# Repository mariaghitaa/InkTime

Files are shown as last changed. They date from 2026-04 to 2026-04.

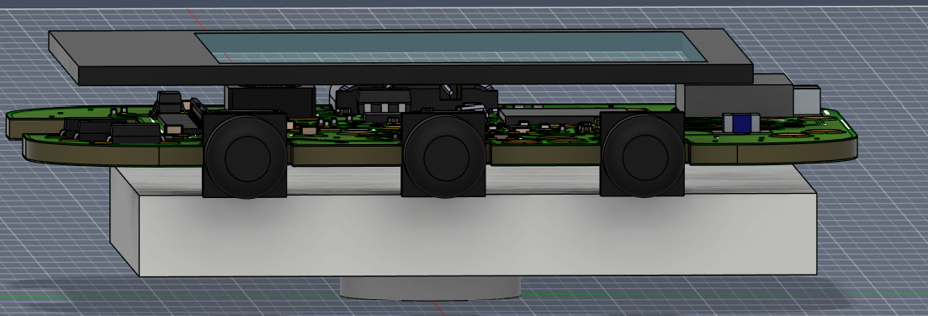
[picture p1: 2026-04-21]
Images/InkTime_asm_without_case.png

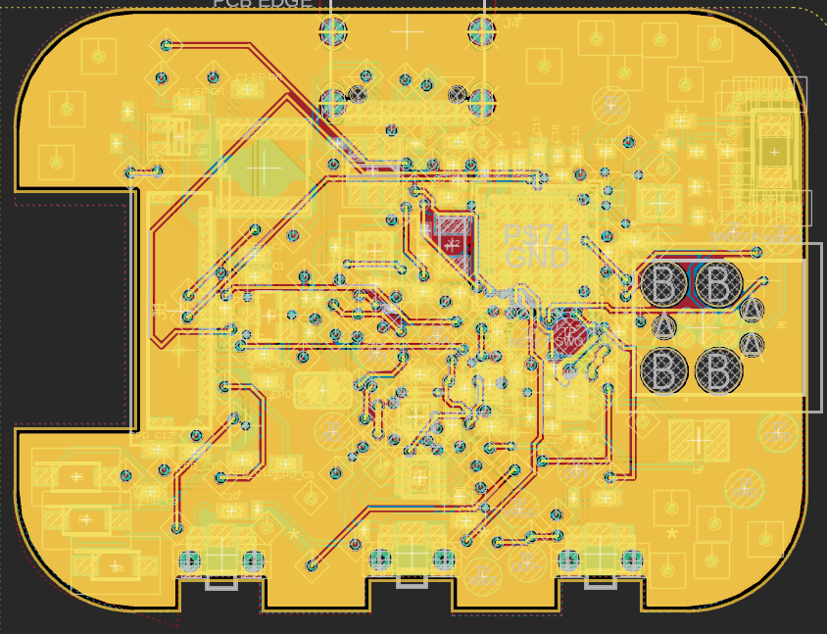
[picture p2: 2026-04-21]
Images/pcb_2D_extralayer.png

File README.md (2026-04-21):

# Proiect InkTime Smartwatch

**Student:** Ghița Maria  
**Grupa:** 331CC

## 1. Descrierea Conceptului

InkTime este un dispozitiv purtabil bazat pe microcontrolerul **nRF52840**, conceput pentru a maximiza autonomia prin utilizarea unui ecran de tip **E-Paper (EPD)** de 1.54 inch. Spre deosebire de ecranele clasice, tehnologia E-Paper consumă energie doar la împrospătarea imaginii, oferind o vizibilitate excelentă în lumină naturală și un mod de operare "Always-on" extrem de eficient.

## 2. Diagrama Bloc (Hardware Architecture)

```text
                                  SISTEM INTELIGENT INKTIME
      SURSA ENERGIE              ___________________________                PERIFERICE (I/O)
    _________________           |                           |             ____________________
   |                 |          |      nRF52840 (SoC)       |            |                    |
   | USB-C Connector |--- 5V ---|   Bluetooth 5.0 Low En.   |--- SPI --->|  E-PAPER DISPLAY   |
   |   (Incarcare)   |          |___________________________|    Bus     |  (1.54" 24-pin)    |
   |_________________|           |  P0.02 (SCK)             |            |____________________|
            |                    |  P0.03 (MOSI)            |
            v                    |  P0.15 (DC)              |             ____________________
    _________________            |  P0.16 (RST)             |            |                    |
   | BQ25180 Charger |           |  P0.17 (BUSY)            |            |                    |
   | (Mngmnt Baterie)|-- VBAT -- |                          |            |                    |
   |_________________|    |      |  P0.26 (SDA) <---I2C---> |----------->|  ACCEL. (BMA421)   |
            ^             |      |  P0.27 (SCL)    Bus      |----------->|  GAUGE (MAX17048)  |
            |             |      |                          |----------->|  DRV2605 (Haptic)  |
    ________|________     |      |                          |            |____________________|
   | Li-Po Battery   |----+      |                          |
   |    250 mAh      |    |      |  P1.11 (PWM) ------------|----------->[ SHAKER / MOTOR ]
   |_________________|    |      |                          |
            |             |      |  P0.13 (UP)              |             ____________________
            v             |      |  P0.14 (ENTER) <---GPIO--|------------|   3x BUTOANE       |
    _________________     |      |  P1.02 (DOWN)            |            |   NAVIGATIE        |
   | RT6160A (Buck-B)|<---+      |                          |            |____________________|
   |  Output: 3.3V   |-----------|  P0.00 / P0.01 ----------|----------->[ CRYSTAL 32.768kHz]
   |_________________|           |  (LFXO Clock)            |            
                                 |__________________________|
```

## 3. Descriere Detaliată Hardware

### 3.1 Microcontroller — nRF52840

Inima sistemului este microcontrollerul Nordic nRF52840, care gestionează toate perifericele, comunicația wireless și logica aplicației.

- **CPU:** ARM Cortex-M4F la frecvență maximă de 64 MHz
- **Memorie:** 1 MB Flash, 256 KB RAM
- **Alimentare:** 3.3V (furnizat de regulatorul DC-DC)
- **Conectivitate:** Bluetooth 5.0 Low Energy, USB 2.0
- **Periferice utilizate:** SPI, I2C, GPIO, PWM, USB

Antena ceramică 2450AT18B100E (2.4 GHz) este acordată printr-o rețea de matching LC calculată pentru impedanță de 50Ω, asigurând performanță RF optimă.

### 3.2 Sistemul de Alimentare

#### Baterie LiPo

Dispozitivul este alimentat de o baterie LiPo cu tensiune nominală de 3.7V (max 4.2V) și capacitate de 250 mAh.

#### Încărcător — BQ25180

Încărcarea bateriei se realizează prin circuitul BQ25180 care primește alimentare de la conectorul USB-C. Acesta oferă management complet al ciclului de încărcare, protecție termică și reglare a curentului de încărcare pentru bateria LiPo. Comunicarea cu MCU-ul se face prin I2C, permițând configurarea parametrilor de încărcare din software.

#### Convertor DC-DC — RT6160A

Regulatorul buck-boost RT6160A convertește tensiunea variabilă a bateriei (3.0–4.2V) într-o ieșire stabilă de 3.3V. Alegerea unui convertor buck-boost (în loc de un LDO) asigură funcționarea stabilă a întregului sistem inclusiv când bateria este aproape descărcată. Tensiunea de 3.3V alimentează MCU-ul, senzorii, display-ul și toate celelalte periferice.

#### Fuel Gauge — MAX17048

Monitorizarea stării bateriei este realizată de MAX17048, care utilizează algoritmul ModelGauge pentru a estima nivelul de încărcare (State of Charge) fără a necesita rezistență de shunt. Comunicarea se face prin I2C, iar pinul ALERT (conectat la P0.10 pe MCU) poate genera o întrerupere atunci când nivelul bateriei scade sub un prag configurat.

### 3.3 Interfața USB-C

Conectorul USB Type-C (KH-TYPE-C-16P) îndeplinește două roluri: alimentare pentru încărcarea bateriei și comunicație USB 2.0 cu MCU-ul. Liniile de date D+ și D- sunt conectate la pinii USB dedicați ai nRF52840, iar pe liniile CC1/CC2 sunt montate rezistențe pull-down de 5.1kΩ pentru identificarea rolului de device. Protecția ESD pe liniile USB este asigurată de circuitul USBLC6-2SC6Y.

### 3.4 Display E-Paper

Display-ul e-paper de 1.54 inch este conectat prin FPC (conector Molex 503480-2400, 24-pin). Principalele avantaje ale tehnologiei e-paper pentru un smartwatch sunt consumul aproape zero în idle (imaginea persistă fără alimentare) și lizibilitatea excelentă în lumina solară.

Comunicarea cu MCU-ul se face prin **SPI** cu următoarele semnale:

- **MOSI** — transmite date și comenzi către display
- **SCK** — semnal de clock pentru sincronizarea transferului
- **DC** — diferențiază între comenzi și date
- **RST** — resetare hardware a controllerului display-ului
- **BUSY** — semnalizează că display-ul procesează un refresh

Alimentarea display-ului este controlată de un PFET Si2301CDS, permițând oprirea completă a panoului pentru economisirea energiei. Circuitul driver integrat pe placa EPD generează tensiunile înalte necesare actualizării cernelii electronice.

### 3.5 Accelerometru — BMA421

Senzorul BMA421 oferă măsurători de accelerație pe 3 axe și este utilizat pentru:

- detecția mișcării și a gesturilor (ridicare încheietură)
- funcționalitate de pedometru
- activarea ecranului din sleep

Comunicarea se face prin **I2C** (SDA, SCL), iar senzorul dispune de două linii de întrerupere (INT1, INT2) care permit trezirea MCU-ului din modul de consum redus doar când apare un eveniment relevant.

### 3.6 Driver Haptic — DRV2605

Driverul DRV2605 controlează motorul de vibrație (LRA/ERM) și oferă o bibliotecă de peste 100 de efecte haptice predefinite. Configurarea efectelor se realizează prin **I2C**, iar activarea vibrației se poate face și direct printr-un semnal digital pe pinul EN, fără a necesita comunicare I2C continuă.

### 3.7 Butoane

Trei butoane tactile (EVP-AKB31A) sunt conectate la pini GPIO ai MCU-ului cu rezistențe pull-up de 10kΩ. La apăsare, butonul conectează pinul la masă, iar MCU-ul detectează tranziția HIGH→LOW. Fiecare buton are un condensator de debouncing de 1µF.

- **UP** — navigare sus în meniu
- **ENTER** — selecție / confirmare
- **DOWN** — navigare jos în meniu

### 3.8 Interfața SWD

Programarea și debugging-ul firmware-ului se realizează prin interfața SWD (Serial Wire Debug) accesibilă printr-un header Tag-Connect TC2030-IDC (6-pin). Semnalele utilizate: SWDIO, SWDCLK, RESET, VCC, GND.

## 4. Bill of Materials (BOM)

| Componentă | Package | JLC Parts | Datasheet |
|---|---|---|---|
| Antenna (2450AT18B100E) | SMD 3216 | [C5179427](https://jlcpcb.com/partdetail/C5179427) | [Datasheet](https://www.johansontechnology.com/datasheets/2450AT18B100/2450AT18B100.pdf) |
| Charger (BQ25120YBGR) | DSBGA-9 | [C1682423](https://jlcpcb.com/partdetail/C1682423) | [Datasheet](https://www.ti.com/lit/ds/symlink/bq25180.pdf) |
| Haptic Driver (DRV2605LDGSR) | VSSOP-10 | [C527464](https://jlcpcb.com/partdetail/C527464) | [Datasheet](https://www.ti.com/lit/ds/symlink/drv2605l.pdf) |
| Buttons (EVP-AKB31A) | SMD tactile | [C2845028](https://jlcpcb.com/partdetail/C2845028) | [Datasheet](https://industrial.panasonic.com/cdbs/www-data/pdf/ATV0000/ATV0000CE3.pdf) |
| USB Type-C Connector (KH-TYPE-C-16P) | 16-pin SMD | [C2765186](https://jlcpcb.com/partdetail/C2765186) | [Datasheet](https://datasheet.lcsc.com/lcsc/2012121836_Kinghelm-KH-TYPE-C-16P_C2765186.pdf) |
| Fuel Gauge (MAX17048G+T10) | DFN-8 (2x2) | [C2682616](https://jlcpcb.com/partdetail/C2682616) | [Datasheet](https://www.analog.com/media/en/technical-documentation/data-sheets/MAX17048-MAX17049.pdf) |
| MCU (nRF52840-QIAA-R) | aQFN73 (7x7) | [C190794](https://jlcpcb.com/partdetail/C190794) | [Datasheet](https://docs.nordicsemi.com/) |
| Accelerometer (BMA421) | LGA-12 (2x2) | [C5242966](https://jlcpcb.com/partdetail/C5242966) | [Datasheet](https://www.bosch-sensortec.com/media/boschsensortec/downloads/datasheets/bst-bma421-ds004.pdf) |
| FPC Connector (Molex 503480-2400) | 24-pin 0.5mm FPC | [C2857168](https://jlcpcb.com/partdetail/C2857168) | [Datasheet](https://www.molex.com/en-us/products/part-detail/5034802400) |
| Buck-Boost Regulator (RT6160AWSC) | WLCSP-15 | [C7065276](https://jlcpcb.com/partdetail/C7065276) | [Datasheet](https://www.richtek.com/assets/product_file/RT6160A/DS6160A-05.pdf) |
| Vibration Motor (LCM102733605F) | Wire leads | [C7528006](https://jlcpcb.com/partdetail/C7528006) | [Datasheet](https://datasheet.lcsc.com/lcsc/2310131633_LCM-LCM1027B3605F_C7528806.pdf) |
| PFET EPD power (Si2301CDS) | SOT-23 | [C10487](https://jlcpcb.com/partdetail/C10487) | [Datasheet](https://www.vishay.com/docs/68749/si2301cds.pdf) |
| USB ESD Protection (USBLC6-2SC6Y) | SOT-23-6 | [C7519](https://jlcpcb.com/partdetail/C7519) | [Datasheet](https://www.st.com/resource/en/datasheet/usblc6-2.pdf) |
| SWD Debug Header (TC2030-IDC) | Tag-Connect 6-pin | - | - |
| Crystal 32 MHz | 2016 | - | - |
| Crystal 32.768 kHz | 3215 | - | - |
| Resistors x 2 10k | 0201 | - | - |
| Resistors x 2 5.1k | 0201 | - | - |
| Capacitors x 4 12pF | 0201 | - | - |
| Capacitors x 5 100nF | 0201 | - | - |
| Capacitors x 5 4.7uF | 0402 | - | - |
| Capacitors x 2 22uF | 0402 | - | - |
| Capacitors x 12 1uF | 0402 | - | - |
| Inductor 0.47uH | 2012 | - | - |
| Inductor 10uH | 0402 | - | - |
| E-Paper Display 1.54 inch | 24-pin FPC | - | - |
| LiPo Battery 250 mAh | - | - | - |

## 5. Alocare Pini nRF52840

### 5.1 Interfața SPI — Display E-Paper

| Pin | Semnal | Rol |
|-----|---|-----|
| P0.02 | SCK | Clock SPI pentru transfer date către display |
| P0.03 | MOSI | Linie de date master → display |
| P0.15 | DC | Selecție date/comandă |
| P0.16 | RST | Reset hardware controller display |
| P0.17 | BUSY | Stare display (ocupat/liber) |

SPI a fost ales deoarece actualizarea display-ului e-paper necesită transferuri rapide de blocuri mari de date (framebuffer complet). Pinii P0.02 și P0.03 suportă mapare SPI flexibilă pe nRF52840, iar P0.15–P0.17 sunt pini GPIO adiacenți, simplificând rutarea pe PCB.

### 5.2 Magistrala I2C — Senzori și Management Energetic

| Pin | Semnal | Dispozitive conectate |
|-----|---|---|
| P0.26 | SDA | BMA421, DRV2605, MAX17048, RT6160A, BQ25180 |
| P0.27 | SCL | BMA421, DRV2605, MAX17048, RT6160A, BQ25180 |

P0.26 și P0.27 sunt pini cu suport hardware I2C nativ (TWIM peripheral) pe nRF52840. Toate cele cinci dispozitive I2C sunt conectate pe aceeași magistrală, fiecare cu adresă unică, reducând numărul de pini utilizați. Pe liniile SDA și SCL sunt montate rezistențe pull-up la 3.3V.

### 5.3 Semnale Suplimentare Senzori

| Pin | Semnal | Rol |
|-----|---|-----|
| P0.10 | ALERT (MAX17048) | Întrerupere la nivel critic baterie, permite trezirea MCU din sleep |
| P0.22 | EN (DRV2605) | Activare directă efect haptic fără comunicație I2C |

Pinii de întrerupere ai BMA421 (INT1, INT2) sunt de asemenea conectați la MCU, permițând detecția evenimentelor de mișcare fără polling continuu.

### 5.4 Butoane — GPIO

| Pin | Funcție | Detalii |
|-----|---|---|
| P0.13 | Button UP | Pull-up 10kΩ, debounce 1µF |
| P0.14 | Button ENTER | Pull-up 10kΩ, debounce 1µF |
| P1.02 | Button DOWN | Pull-up 10kΩ, debounce 1µF |

Pinii sunt configurați ca intrări digitale. Alegerea lor a ținut cont de disponibilitatea pe portul GPIO și de rutarea optimă pe PCB. Apăsarea butonului trage pinul la GND, iar MCU-ul detectează frontul descrescător.

### 5.5 USB

| Pin | Semnal |
|-----|---|
| D+ (dedicat) | Linie de date USB+ |
| D- (dedicat) | Linie de date USB- |
| VBUS (dedicat) | Detecție alimentare USB |

Pinii USB sunt dedicați pe nRF52840 (nu sunt GPIO remapabili) și sunt conectați la conectorul USB-C prin circuitul de protecție ESD USBLC6-2SC6Y.

### 5.6 Alte Semnale

| Pin | Semnal | Rol |
|-----|---|-----|
| P0.00 | XL1 | Cristal 32.768 kHz — clock RTC pentru timekeeping în sleep |
| P0.01 | XL2 | Cristal 32.768 kHz — pereche oscilator LFXO |
| SWDIO | SWD Data | Programare și debug firmware |
| SWDCLK | SWD Clock | Clock interfață debug |

P0.00 și P0.01 sunt singurii pini pe nRF52840 dedicați oscilatorului low-frequency (LFXO). Cristalul de 32.768 kHz permite funcționarea RTC-ului cu consum extrem de redus (~2 µA) în modul System ON sleep.

### 5.7 Criterii de Alocare

Distribuția pinilor a fost realizată ținând cont de:

- utilizarea interfețelor hardware native ale MCU-ului (SPI, I2C, USB, LFXO)
- gruparea semnalelor conexe pe pini adiacenți pentru simplificarea traseelor PCB
- disponibilitatea funcțiilor de întrerupere hardware pe pinii aleși
- minimizarea consumului prin posibilitatea de wake-up din sleep pe oricare din pinii GPIO utilizați

## 6. Estimare Consum de Energie

### Consum per componentă

| Componentă | Mod Sleep / Idle | Mod Activ |
|---|---|---|
| nRF52840 | ~2–5 µA (System ON sleep) | ~5–10 mA (CPU activ, radio oprit) |
| nRF52840 (BLE TX) | — | ~4.8 mA (transmisie la 0 dBm) |
| Display E-Paper | ~0 µA (imagine statică) | ~10–20 mA (în timpul refresh-ului) |
| BMA421 | ~14 µA (low-power mode) | ~160 µA (normal mode) |
| MAX17048 | ~50 µA (măsurare continuă) | ~50 µA |
| DRV2605 + Motor | ~0 µA (standby) | ~100 mA (vibrație activă) |
| RT6160A | ~15 µA (quiescent) | depinde de sarcină |
| BQ25180 | ~1 µA (mod ship) | depinde de curentul de încărcare |

### Scenariu tipic de utilizare

În funcționare normală (ecran static, BLE inactiv, fără vibrație), consumul este dominat de MCU în sleep și senzori:

| Componentă | Consum estimat |
|---|---|
| MCU (sleep cu RTC) | ~5 µA |
| BMA421 (low-power) | ~14 µA |
| MAX17048 | ~50 µA |
| RT6160A (quiescent) | ~15 µA |
| **Total idle** | **~84 µA** |

Cu o baterie de 250 mAh, autonomia teoretică maximă în idle este:

**250.000 µAh / 84 µA ≈ 2.976 ore ≈ 124 zile**

Într-un scenariu realist (cu refresh-uri periodice ale ecranului, citiri BLE ocazionale și notificări haptice), consumul mediu estimat este de aproximativ **0.5–1 mA**, rezultând o autonomie de **10–20 zile** — competitivă cu smartwatch-urile e-paper comerciale.

## 7. Jurnal de Design și Fabricație

- **Proiectare PCB:** S-a optat pentru o configurație de 4 straturi (Signal-GND-VCC-Signal) pentru a asigura ecranarea electromagnetică și integritatea semnalului RF.
- **Miniaturizare:** Toate componentele pasive de decuplare din jurul nRF52840 sunt de mărime 0201, reducând dimensiunea finală a plăcii.
- **Design Mecanic:** Carcasa a fost modelată în Fusion 360 pentru a integra PCB-ul și bateria de 250mAh într-un profil compact, utilizând toleranțe strânse pentru montarea prin presare.

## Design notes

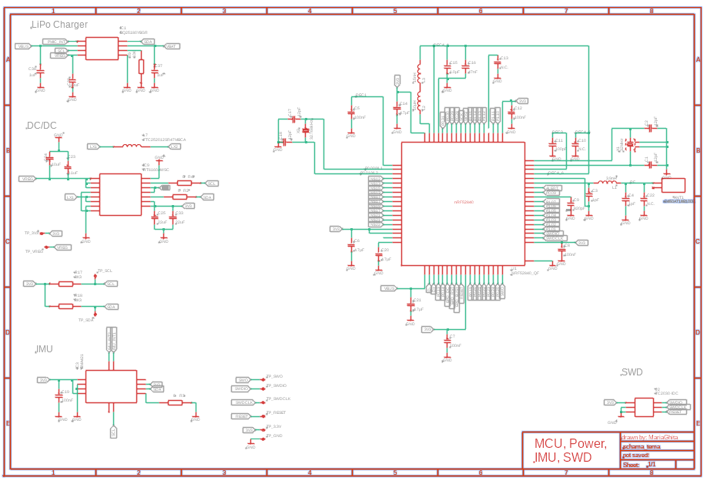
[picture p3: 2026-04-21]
Images/schematic_1.png

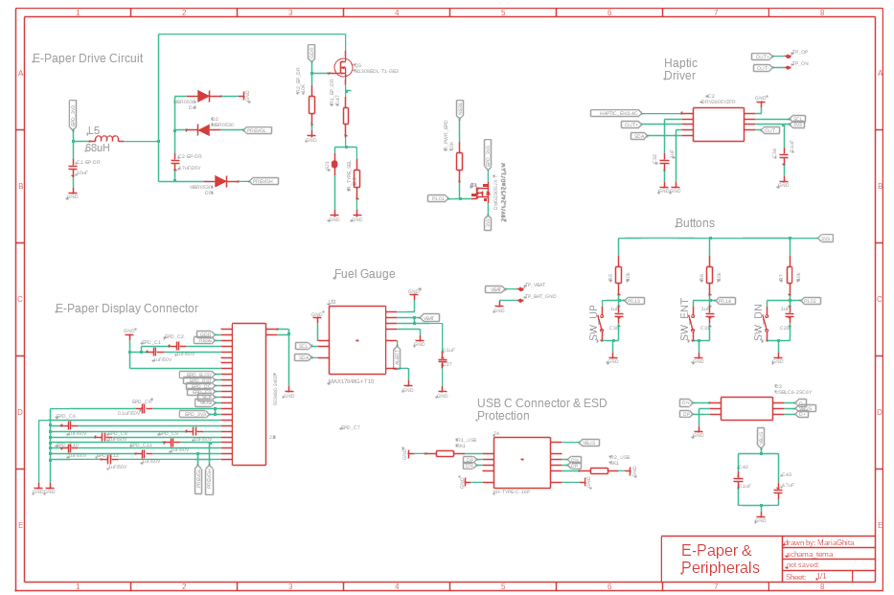
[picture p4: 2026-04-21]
Images/schematic_2.png

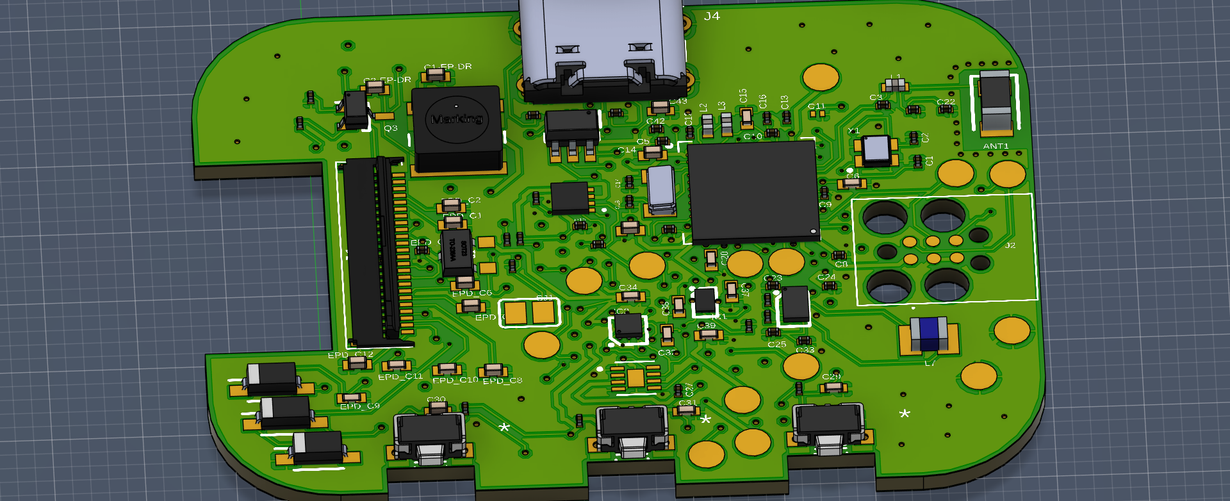
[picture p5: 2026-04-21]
Images/pcb_3D_top.png

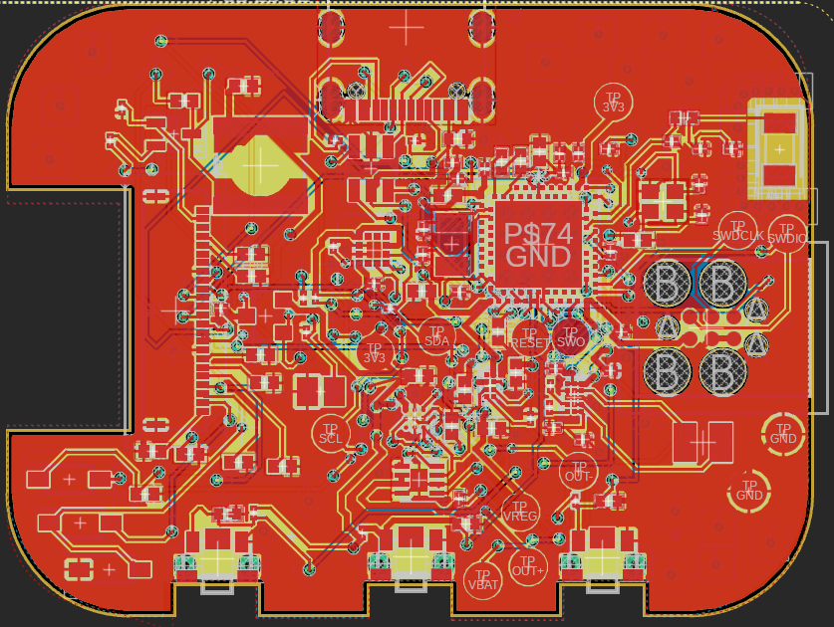
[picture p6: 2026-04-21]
Images/pcb_2D_top.png

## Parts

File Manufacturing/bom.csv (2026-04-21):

Part | Value | Device | Package | Description | ARROW_PART_NUMBER | ARROW_PRICE-STOCK | AVAILABILITY | CHECK_PRICES | COPYRIGHT | DESCRIPTION | DIGI-KEY_PART_NUMBER_1 | DIGI-KEY_PART_NUMBER_2 | DIGI-KEY_PART_NUMBER_3 | HEIGHT | JLCPCB | MANUFACTURER_NAME | MANUFACTURER_PART_NUMBER | MF | MFR_NAME | MOUSER_PART_NUMBER | MOUSER_PRICE-STOCK | MP | PACKAGE | POPULARITY | PRICE | PROD_ID | PURCHASE-URL | SNAPEDA_LINK | TP_SIGNAL_NAME | VALUE
ANT1 | 2450AT18B100E | 2450AT18B100E_2450AT18B100E | 2450AT18B100E_ANTC3216X140N | Antennas 2.45GHz ANTENNA | 2450AT18B100E | https://www.arrow.com/en/products/2450at18b100e/johanson-dielectrics?utm_currency=USD&region=nac |  |  |  | Antennas 2.45GHz ANTENNA |  |  |  | 1.4mm |  | JOHANSON TECHNOLOGY | 2450AT18B100E |  |  | 609-2450AT18B100E | https://www.mouser.co.uk/ProductDetail/Johanson-Technology/2450AT18B100E?qs=yCnrNFeXz%252Bh5MFsFIXGZGA%3D%3D
C1 | 12pF | NORDIC_NRF_3_CAPACITOR_0201_L | NORDIC_NRF_3_RESC0201_L | Generic chip capacitor
C1-EP-DR | 10uF | PERFECT_0402_CAP_0402 | PERFECT_0402_0402 | 0402 (1005 Metric)
C2 | 12pF | NORDIC_NRF_3_CAPACITOR_0201_L | NORDIC_NRF_3_RESC0201_L | Generic chip capacitor
C2-EP-DR | 4.7uF/25V | PERFECT_0402_CAP_0402 | PERFECT_0402_0402 | 0402 (1005 Metric)
C3 | 1pF | NORDIC_NRF_3_CAPACITOR_0201_L | NORDIC_NRF_3_RESC0201_L | Generic chip capacitor
C4 | 1pF | NORDIC_NRF_3_CAPACITOR_0201_L | NORDIC_NRF_3_RESC0201_L | Generic chip capacitor
C5 | 100nF | NORDIC_NRF_3_CAPACITOR_0201_L | NORDIC_NRF_3_RESC0201_L | Generic chip capacitor
C6 | 4.7µF | PERFECT_0402_CAP_0402 | PERFECT_0402_0402 | 0402 (1005 Metric)
C7 | 100nF | NORDIC_NRF_3_CAPACITOR_0201_L | NORDIC_NRF_3_RESC0201_L | Generic chip capacitor
C8 | 100nF | NORDIC_NRF_3_CAPACITOR_0201_L | NORDIC_NRF_3_RESC0201_L | Generic chip capacitor
C9 | 820pF | NORDIC_NRF_3_CAPACITOR_0201_L | NORDIC_NRF_3_RESC0201_L | Generic chip capacitor
C10 | N.C. | NORDIC_NRF_3_CAPACITOR_0201_L | NORDIC_NRF_3_RESC0201_L | Generic chip capacitor
C11 | 100pF | NORDIC_NRF_3_CAPACITOR_0201_L | NORDIC_NRF_3_RESC0201_L | Generic chip capacitor
C12 | 100nF | NORDIC_NRF_3_CAPACITOR_0201_L | NORDIC_NRF_3_RESC0201_L | Generic chip capacitor
C13 | N.C. | NORDIC_NRF_3_CAPACITOR_0201_L | NORDIC_NRF_3_RESC0201_L | Generic chip capacitor
C14 | 4.7µF | PERFECT_0402_CAP_0402 | PERFECT_0402_0402 | 0402 (1005 Metric)
C15 | 1.0µF | PERFECT_0402_CAP_0402 | PERFECT_0402_0402 | 0402 (1005 Metric)
C16 | 47nF | NORDIC_NRF_3_CAPACITOR_0201_L | NORDIC_NRF_3_RESC0201_L | Generic chip capacitor
C17 | 12pF | NORDIC_NRF_3_CAPACITOR_0201_L | NORDIC_NRF_3_RESC0201_L | Generic chip capacitor
C18 | 12pF | NORDIC_NRF_3_CAPACITOR_0201_L | NORDIC_NRF_3_RESC0201_L | Generic chip capacitor
C19 | 100nF | NORDIC_NRF_3_CAPACITOR_0201_L | NORDIC_NRF_3_RESC0201_L | Generic chip capacitor
C20 | 4.7µF | PERFECT_0402_CAP_0402 | PERFECT_0402_0402 | 0402 (1005 Metric)
C21 | 4.7µF | PERFECT_0402_CAP_0402 | PERFECT_0402_0402 | 0402 (1005 Metric)
C22 | N.C. | NORDIC_NRF_3_CAPACITOR_0201_L | NORDIC_NRF_3_RESC0201_L | Generic chip capacitor
C23 | 0.1uF | NORDIC_NRF_3_CAPACITOR_0201_L | NORDIC_NRF_3_RESC0201_L | Generic chip capacitor
C24 | 10uF | NORDIC_NRF_3_CAPACITOR_0201_L | NORDIC_NRF_3_RESC0201_L | Generic chip capacitor
C25 | 22uF | NORDIC_NRF_3_CAPACITOR_0201_L | NORDIC_NRF_3_RESC0201_L | Generic chip capacitor
C27 | 0.1uF | NORDIC_NRF_3_CAPACITOR_0201_L | NORDIC_NRF_3_RESC0201_L | Generic chip capacitor
C29 | 1uF | NORDIC_NRF_3_CAPACITOR_0402_L | NORDIC_NRF_3_RESC0402_L | Generic chip capacitor
C30 | 1uF | NORDIC_NRF_3_CAPACITOR_0402_L | NORDIC_NRF_3_RESC0402_L | Generic chip capacitor
C31 | 1uF | NORDIC_NRF_3_CAPACITOR_0402_L | NORDIC_NRF_3_RESC0402_L | Generic chip capacitor
C32 | 1uF | PERFECT_0402_CAP_0402 | PERFECT_0402_0402 | 0402 (1005 Metric)
C33 | 22uF | NORDIC_NRF_3_CAPACITOR_0201_L | NORDIC_NRF_3_RESC0201_L | Generic chip capacitor
C34 | 0.1uF | PERFECT_0402_CAP_0402 | PERFECT_0402_0402 | 0402 (1005 Metric)
C37 | 1uF | PERFECT_0402_CAP_0402 | PERFECT_0402_0402 | 0402 (1005 Metric)
C38 | 1uF | PERFECT_0402_CAP_0402 | PERFECT_0402_0402 | 0402 (1005 Metric)
C39 | 10uF | PERFECT_0402_CAP_0402 | PERFECT_0402_0402 | 0402 (1005 Metric)
C42 | 0.1uF | NORDIC_NRF_3_CAPACITOR_0201_L | NORDIC_NRF_3_RESC0201_L | Generic chip capacitor
C43 | 4.7uF | NORDIC_NRF_3_CAPACITOR_0402_L | NORDIC_NRF_3_RESC0402_L | Generic chip capacitor
D2 | MBR0530 | ESP32_C6_LIBRARY_5_MBR0530 | ESP32_C6_LIBRARY_5_SOD3716X135N | ON SEMICONDUCTOR - MBR0530 - DIODE, SCHOTTKY, 0.5A, 30V, SOD-123 |  |  | In Stock | https://www.snapeda.com/parts/MBR0530/Onsemi/view-part/?ref=eda |  | Diode Schottky 30 V 500mA Surface Mount SOD-123 |  |  |  |  |  |  |  | ON Semiconductor |  |  |  | MBR0530 | SOD-123-2 ON Semiconductor |  | None |  | https://www.snapeda.com/api/url_track_click_mouser/?unipart_id=179458&manufacturer=ON Semiconductor&part_name=MBR0530&search_term=None | https://www.snapeda.com/parts/MBR0530/Onsemi/view-part/?ref=snap
D3 | USBLC6-2SC6Y | ESP32_C6_LIBRARY_3_USBLC6-2SC6Y | ESP32_C6_LIBRARY_3_SOT95P280X145-6N | Low Cap. ESD Protection Auto SOT-23-6 STMicroelectronics USBLC6-2SC6Y, Dual Uni-Directional TVS Diode Array, 6-Pin SOT-23 |  |  | In Stock | https://www.snapeda.com/parts/USBLC6-2SC6Y/STMicroelectronics/view-part/?ref=eda |  | 17V Clamp 5A (8/20µs) Ipp Tvs Diode Surface Mount SOT-23-6 |  |  |  |  |  |  |  | STMicroelectronics |  |  |  | USBLC6-2SC6Y | SOT-23-6 STMicroelectronics |  | None |  |  | https://www.snapeda.com/parts/USBLC6-2SC6Y/STMicroelectronics/view-part/?ref=snap
D4 | MBR0530 | ESP32_C6_LIBRARY_5_MBR0530 | ESP32_C6_LIBRARY_5_SOD3716X135N | ON SEMICONDUCTOR - MBR0530 - DIODE, SCHOTTKY, 0.5A, 30V, SOD-123 |  |  | In Stock | https://www.snapeda.com/parts/MBR0530/Onsemi/view-part/?ref=eda |  | Diode Schottky 30 V 500mA Surface Mount SOD-123 |  |  |  |  |  |  |  | ON Semiconductor |  |  |  | MBR0530 | SOD-123-2 ON Semiconductor |  | None |  | https://www.snapeda.com/api/url_track_click_mouser/?unipart_id=179458&manufacturer=ON Semiconductor&part_name=MBR0530&search_term=None | https://www.snapeda.com/parts/MBR0530/Onsemi/view-part/?ref=snap
D5 | MBR0530 | ESP32_C6_LIBRARY_5_MBR0530 | ESP32_C6_LIBRARY_5_SOD3716X135N | ON SEMICONDUCTOR - MBR0530 - DIODE, SCHOTTKY, 0.5A, 30V, SOD-123 |  |  | In Stock | https://www.snapeda.com/parts/MBR0530/Onsemi/view-part/?ref=eda |  | Diode Schottky 30 V 500mA Surface Mount SOD-123 |  |  |  |  |  |  |  | ON Semiconductor |  |  |  | MBR0530 | SOD-123-2 ON Semiconductor |  | None |  | https://www.snapeda.com/api/url_track_click_mouser/?unipart_id=179458&manufacturer=ON Semiconductor&part_name=MBR0530&search_term=None | https://www.snapeda.com/parts/MBR0530/Onsemi/view-part/?ref=snap
EPD_C1 | 1uF/50V | PERFECT_0402_CAP_0402 | PERFECT_0402_0402 | 0402 (1005 Metric)
EPD_C2 | 1uF/50V | PERFECT_0402_CAP_0402 | PERFECT_0402_0402 | 0402 (1005 Metric)
EPD_C5 | 0.1uF/50V | NORDIC_NRF_3_CAPACITOR_0201_L | NORDIC_NRF_3_RESC0201_L | Generic chip capacitor
EPD_C6 | 1uF/50V | PERFECT_0402_CAP_0402 | PERFECT_0402_0402 | 0402 (1005 Metric)
EPD_C7 | 1uF/50V | PERFECT_0402_CAP_0402 | PERFECT_0402_0402 | 0402 (1005 Metric)
EPD_C8 | 1uF/50V | PERFECT_0402_CAP_0402 | PERFECT_0402_0402 | 0402 (1005 Metric)
EPD_C9 | 1uF/50V | PERFECT_0402_CAP_0402 | PERFECT_0402_0402 | 0402 (1005 Metric)
EPD_C10 | 1uF/50V | PERFECT_0402_CAP_0402 | PERFECT_0402_0402 | 0402 (1005 Metric)
EPD_C11 | 1uF/50V | PERFECT_0402_CAP_0402 | PERFECT_0402_0402 | 0402 (1005 Metric)
EPD_C12 | 1uF/50V | PERFECT_0402_CAP_0402 | PERFECT_0402_0402 | 0402 (1005 Metric)
IC1 | BQ25180YBGR | BQ25180YBGR_BQ25180YBGR | BQ25180YBGR_BGA8C40P2X4_100X155X50 | Charger IC Lithium Ion/Polymer, Lithium Iron Phosphate 8-DSBGA (1.6x1.1) | BQ25180YBGR | https://www.arrow.com/en/products/bq25180ybgr/texas-instruments?utm_currency=USD&region=nac |  |  |  | Charger IC Lithium Ion/Polymer | Lithium Iron Phosphate 8-DSBGA (1.6x1.1) |  |  |  | 0.5mm |  | Texas Instruments | BQ25180YBGR |  |  | 595-BQ25180YBGR | https://www.mouser.co.uk/ProductDetail/Texas-Instruments/BQ25180YBGR?qs=doiCPypUmgEWjAK%252BJAX6Tw%3D%3D
IC2 | DRV2605YZFR | DRV2605YZFR_DRV2605YZFR | DRV2605YZFR_BGA9C50P3X3_144X144X62 | Haptic Driver for ERM/LRA with Built-In Library and Smart Loop Architecture | DRV2605YZFR | https://www.arrow.com/en/products/drv2605yzfr/texas-instruments?region=nac |  |  |  | Haptic Driver for ERM/LRA with Built-In Library and Smart Loop Architecture |  |  |  | 0.625mm |  | Texas Instruments | DRV2605YZFR
IC3 | BMA421 | BMA423_BMA423 | BMA423_BMA423 | Accelerometers Triaxial low-g 12bit Acceleration Sensor | BMA423 | https://www.arrow.com/en/products/bma423/bosch |  |  |  | Accelerometers Triaxial low-g 12bit Acceleration Sensor |  |  |  | 1mm |  | BOSCH | BMA423 |  |  | 262-BMA423 | https://www.mouser.co.uk/ProductDetail/Bosch-Sensortec/BMA423?qs=HXFqYaX1Q2xC%252BSgeGoX3mg%3D%3D
IC9 | RT6160AWSC | RT6160AWSC_RT6160AWSC | RT6160AWSC_BGA15C40P3X5_140X230X60 | Buck-Boost Regulator Positive Output Step-Up/Step-Down I2C DC-DC Controller IC 15-WL-CSP (BSC) (1.4x2.3) |  |  |  |  |  | Buck-Boost Regulator Positive Output Step-Up/Step-Down I2C DC-DC Controller IC 15-WL-CSP (BSC) (1.4x2.3) |  |  |  | 0.6mm |  | RICHTEK | RT6160AWSC |  |  | 835-RT6160AWSC | https://www.mouser.co.uk/ProductDetail/Richtek/RT6160AWSC?qs=amGC7iS6iy%2FLd9PSoixZXQ%3D%3D
J1 | 503480-2400 | 503480-2400_503480-2400 | 503480-2400_5034802400 | FFC & FPC Connectors 0.5mm FPC RA SMT Dual Contact 24Ckt |  |  |  |  |  | FFC & FPC Connectors 0.5mm FPC RA SMT Dual Contact 24Ckt |  |  |  | 1.87mm |  | Molex | 503480-2400 |  |  | 538-503480-2400 | https://www.mouser.co.uk/ProductDetail/Molex/503480-2400?qs=OAhjpuo3Vu7efIoxFh9AOw%3D%3D
J2 | TC2030-IDC | TC2030-IDC_TC2030-IDC | TC2030-IDC_TC2030IDC | CABLE ADAPTER 6 POS |  |  |  |  |  | CABLE ADAPTER 6 POS |  |  |  | 19mm |  | Tag Connect | TC2030-IDC
J4 | KH-TYPE-C-16P | KH-TYPE-C-16P_KH-TYPE-C-16P | KH-TYPE-C-16P_KINGHELM_KH-TYPE-C-16P | Check availability |  |  | Not in stock | https://www.snapeda.com/parts/KH-TYPE-C-16P/Kinghelm/view-part/?ref=eda |  |  |  |  |  |  |  |  |  | kinghelm |  |  |  | KH-TYPE-C-16P | None |  | None |  |  | https://www.snapeda.com/parts/KH-TYPE-C-16P/Kinghelm/view-part/?ref=snap
L1 | 3.9nH | NORDIC_NRF_2_INDUCTOR_0402_L | NORDIC_NRF_2_RESC0402_L | Generic chip inductor
L2 | 10µH | NORDIC_NRF_2_INDUCTOR_0402_L | NORDIC_NRF_2_RESC0402_L | Generic chip inductor
L3 | 15nH | NORDIC_NRF_2_INDUCTOR_0402_L | NORDIC_NRF_2_RESC0402_L | Generic chip inductor
L5 | 68uH | ESP32_C6_LIBRARY_2_744043680IND_4828-WE-TPC_WRE | ESP32_C6_LIBRARY_2_IND_4828-WE-TPC_WRE |  |  |  |  |  | Copyright (C) 2024 Ultra Librarian. All rights reserved. |  |  |  |  |  |  |  | 744043680 |  | Wurth Electronics
L7 | FTC252012SR47MBCA | MLP2016SR47MT0S1_FTC252012SR47MBCA | MLP2016SR47MT0S1_INDC2016X100N | SMD / SMT Inductors (Coils), L=0.47?H, L x W x T : |  |  |  |  |  | SMD / SMT Inductors (Coils) | L=0.47?H | L x W x T : |  |  |  | 1mm | https://jlcpcb.com/partdetail/6763488-FTC252012SR47MBCA/C5832368 | TDK | FTC252012SR47MBCA
Q1 | 20V/4.2A/52mO/1.4W | ESP32_C6_LIBRARY_4_ESP32_WROVER_SPARKFUN-DISCRETESEMI_MOSFET_PCH-DMG2305UX-7 | ESP32_C6_LIBRARY_4_ESP32_C6_LIBRARY_4_ESP32_C6_LIBRARY_4_ESP32_C6_LIBRARY_4_ESP32_WROVER_SPARKFUN-DISCRETESEMI_SOT23-3 | P-channel MOSFETs |  |  |  |  |  |  |  |  |  |  |  |  |  |  |  |  |  |  |  |  |  | TRAN-14388 |  |  |  | 20V/4.2A/52mO/1.4W
Q3 | SI1308EDL-T1-GE3 | ESP32_C6_LIBRARY_6_SI1308EDL-T1-GE3 | ESP32_C6_LIBRARY_6_SOT65P210X110-3N | MOSFET N-Ch 30V 1.5A TrenchFET SC70 Vishay Si1308EDL-T1-GE3 N-channel MOSFET Transistor, 1.5 A, 30 V, 3-Pin SC-70 |  |  | In Stock | https://www.snapeda.com/parts/SI1308EDL-T1-GE3/Vishay+Siliconix/view-part/?ref=eda |  | Si1308EDL-T1-GE3 N-channel MOSFET Transistor | 1.5 A | 30 V | 3-Pin SC-70 | Siliconix / Vishay SI1308EDL-T1-GE3 |  |  |  |  |  |  |  | Vishay Siliconix |  |  |  | SI1308EDL-T1-GE3 | SOT-323 Vishay Semiconductor |  | None |  | https://www.snapeda.com/api/url_track_click_mouser/?unipart_id=274603&manufacturer=Vishay Siliconix&part_name=SI1308EDL-T1-GE3&search_term=None
R1_EP_DR | 0.47 | CPF0201D7K68C1_CPF0201D7K68C1 | CPF0201D7K68C1_0201 | 7.68k 0201 Thin Film Surface Mount Fixed Resistor +/-0.5% 0.031W CPF0201D7K68C1
R1_USB | 5K1 | CPF0201D7K68C1_CPF0201D7K68C1 | CPF0201D7K68C1_0201 | 7.68k 0201 Thin Film Surface Mount Fixed Resistor +/-0.5% 0.031W CPF0201D7K68C1
R2 | 0 | CPF0201D7K68C1_CPF0201D7K68C1 | CPF0201D7K68C1_0201 | 7.68k 0201 Thin Film Surface Mount Fixed Resistor +/-0.5% 0.031W CPF0201D7K68C1
R2_EP_DR | 10K | CPF0201D7K68C1_CPF0201D7K68C1 | CPF0201D7K68C1_0201 | 7.68k 0201 Thin Film Surface Mount Fixed Resistor +/-0.5% 0.031W CPF0201D7K68C1
R2_USB | 5K1 | CPF0201D7K68C1_CPF0201D7K68C1 | CPF0201D7K68C1_0201 | 7.68k 0201 Thin Film Surface Mount Fixed Resistor +/-0.5% 0.031W CPF0201D7K68C1
R3 | 0 | CPF0201D7K68C1_CPF0201D7K68C1 | CPF0201D7K68C1_0201 | 7.68k 0201 Thin Film Surface Mount Fixed Resistor +/-0.5% 0.031W CPF0201D7K68C1
R4 | 0 | CPF0201D7K68C1_CPF0201D7K68C1 | CPF0201D7K68C1_0201 | 7.68k 0201 Thin Film Surface Mount Fixed Resistor +/-0.5% 0.031W CPF0201D7K68C1
R5 | 10k | CPF0201D7K68C1_CPF0201D7K68C1 | CPF0201D7K68C1_0201 | 7.68k 0201 Thin Film Surface Mount Fixed Resistor +/-0.5% 0.031W CPF0201D7K68C1
R7 | 10k | CPF0201D7K68C1_CPF0201D7K68C1 | CPF0201D7K68C1_0201 | 7.68k 0201 Thin Film Surface Mount Fixed Resistor +/-0.5% 0.031W CPF0201D7K68C1
R8 | 10k | CPF0201D7K68C1_CPF0201D7K68C1 | CPF0201D7K68C1_0201 | 7.68k 0201 Thin Film Surface Mount Fixed Resistor +/-0.5% 0.031W CPF0201D7K68C1
R9 | 10K | CPF0201D7K68C1_CPF0201D7K68C1 | CPF0201D7K68C1_0201 | 7.68k 0201 Thin Film Surface Mount Fixed Resistor +/-0.5% 0.031W CPF0201D7K68C1
R17 | 3K3 | CPF0201D7K68C1_CPF0201D7K68C1 | CPF0201D7K68C1_0201 | 7.68k 0201 Thin Film Surface Mount Fixed Resistor +/-0.5% 0.031W CPF0201D7K68C1
R18 | 3K3 | CPF0201D7K68C1_CPF0201D7K68C1 | CPF0201D7K68C1_0201 | 7.68k 0201 Thin Film Surface Mount Fixed Resistor +/-0.5% 0.031W CPF0201D7K68C1
R_PWR_EPD | 10K | CPF0201D7K68C1_CPF0201D7K68C1 | CPF0201D7K68C1_0201 | 7.68k 0201 Thin Film Surface Mount Fixed Resistor +/-0.5% 0.031W CPF0201D7K68C1
R_TYPE_SEL | 2.2 | CPF0201D7K68C1_CPF0201D7K68C1 | CPF0201D7K68C1_0201 | 7.68k 0201 Thin Film Surface Mount Fixed Resistor +/-0.5% 0.031W CPF0201D7K68C1
SJ1 |  | ESP32_C6_LIBRARY_7_JUMPER_SJ | ESP32_C6_LIBRARY_7_JUMPER_SJ | SMD solder JUMPER |  |  |  |  |  |  |  |  |  |  |  |  |  |  |  |  |  |  |  | 3
SW_DN | 2025-10-22_07-23-44_LIBRARY_EVP-AKE31ASW_EVP-AKE31A_PAN | 2025-10-22_07-23-44_LIBRARY_EVP-AKE31ASW_EVP-AKE31A_PAN | 2025-10-22_07-23-44_LIBRARY_SW_EVP-AKE31A_PAN |  |  |  |  |  | Copyright (C) 2025 Ultra Librarian. All rights reserved. |  | P123437TR-ND | P123437CT-ND | P123437DKR-ND |  |  | Panasonic | EVP-AKE31A
SW_ENT | 2025-10-22_07-23-44_LIBRARY_EVP-AKE31ASW_EVP-AKE31A_PAN | 2025-10-22_07-23-44_LIBRARY_EVP-AKE31ASW_EVP-AKE31A_PAN | 2025-10-22_07-23-44_LIBRARY_SW_EVP-AKE31A_PAN |  |  |  |  |  | Copyright (C) 2025 Ultra Librarian. All rights reserved. |  | P123437TR-ND | P123437CT-ND | P123437DKR-ND |  |  | Panasonic | EVP-AKE31A
SW_UP | 2025-10-22_07-23-44_LIBRARY_EVP-AKE31ASW_EVP-AKE31A_PAN | 2025-10-22_07-23-44_LIBRARY_EVP-AKE31ASW_EVP-AKE31A_PAN | 2025-10-22_07-23-44_LIBRARY_SW_EVP-AKE31A_PAN |  |  |  |  |  | Copyright (C) 2025 Ultra Librarian. All rights reserved. |  | P123437TR-ND | P123437CT-ND | P123437DKR-ND |  |  | Panasonic | EVP-AKE31A
TP_3.3V | HECTOR_WATCH_1_TPTP20R | HECTOR_WATCH_1_TPTP20R | HECTOR_WATCH_1_TP20R | Test pad |  |  |  |  |  |  |  |  |  |  |  |  |  |  |  |  |  |  |  | 2
TP_3V3 | HECTOR_WATCH_1_TPTP20R | HECTOR_WATCH_1_TPTP20R | HECTOR_WATCH_1_TP20R | Test pad |  |  |  |  |  |  |  |  |  |  |  |  |  |  |  |  |  |  |  | 2
TP_BAT_GND | HECTOR_WATCH_1_TPTP20R | HECTOR_WATCH_1_TPTP20R | HECTOR_WATCH_1_TP20R | Test pad |  |  |  |  |  |  |  |  |  |  |  |  |  |  |  |  |  |  |  | 2
TP_GND | HECTOR_WATCH_1_TPTP20R | HECTOR_WATCH_1_TPTP20R | HECTOR_WATCH_1_TP20R | Test pad |  |  |  |  |  |  |  |  |  |  |  |  |  |  |  |  |  |  |  | 2
TP_ON | HECTOR_WATCH_1_TPTP20R | HECTOR_WATCH_1_TPTP20R | HECTOR_WATCH_1_TP20R | Test pad |  |  |  |  |  |  |  |  |  |  |  |  |  |  |  |  |  |  |  | 2
TP_OP | HECTOR_WATCH_1_TPTP20R | HECTOR_WATCH_1_TPTP20R | HECTOR_WATCH_1_TP20R | Test pad |  |  |  |  |  |  |  |  |  |  |  |  |  |  |  |  |  |  |  | 2
TP_RESET | HECTOR_WATCH_1_TPTP20R | HECTOR_WATCH_1_TPTP20R | HECTOR_WATCH_1_TP20R | Test pad |  |  |  |  |  |  |  |  |  |  |  |  |  |  |  |  |  |  |  | 2
TP_SCL | HECTOR_WATCH_1_TPTP20R | HECTOR_WATCH_1_TPTP20R | HECTOR_WATCH_1_TP20R | Test pad |  |  |  |  |  |  |  |  |  |  |  |  |  |  |  |  |  |  |  | 2
TP_SDA | HECTOR_WATCH_1_TPTP20R | HECTOR_WATCH_1_TPTP20R | HECTOR_WATCH_1_TP20R | Test pad |  |  |  |  |  |  |  |  |  |  |  |  |  |  |  |  |  |  |  | 2
TP_SWDCLK | HECTOR_WATCH_1_TPTP20R | HECTOR_WATCH_1_TPTP20R | HECTOR_WATCH_1_TP20R | Test pad |  |  |  |  |  |  |  |  |  |  |  |  |  |  |  |  |  |  |  | 2
TP_SWDIO | HECTOR_WATCH_1_TPTP20R | HECTOR_WATCH_1_TPTP20R | HECTOR_WATCH_1_TP20R | Test pad |  |  |  |  |  |  |  |  |  |  |  |  |  |  |  |  |  |  |  | 2
TP_SWO | HECTOR_WATCH_1_TPTP20R | HECTOR_WATCH_1_TPTP20R | HECTOR_WATCH_1_TP20R | Test pad |  |  |  |  |  |  |  |  |  |  |  |  |  |  |  |  |  |  |  | 2
TP_VBAT | HECTOR_WATCH_1_TPTP20R | HECTOR_WATCH_1_TPTP20R | HECTOR_WATCH_1_TP20R | Test pad |  |  |  |  |  |  |  |  |  |  |  |  |  |  |  |  |  |  |  | 2
TP_VREG | HECTOR_WATCH_1_TPTP20R | HECTOR_WATCH_1_TPTP20R | HECTOR_WATCH_1_TP20R | Test pad |  |  |  |  |  |  |  |  |  |  |  |  |  |  |  |  |  |  |  | 2
U1 | NRF52840_QF | NORDIC_NRF_4_NRF52840_QF | NORDIC_NRF_4_AQFN50P700X700X85_HS-74N | nRF52840
U3 | MAX17048G+T10 | ESP32_C6_LIBRARY_MAX17048G+T10 | ESP32_C6_LIBRARY_SON50P200X200X80-9N | Check availability |  |  | In Stock | https://www.snapeda.com/parts/MAX17048G+T10/Analog+Devices/view-part/?ref=eda |  | 3µA 1-Cell/2-Cell Fuel Gauge with ModelGauge |  |  |  |  |  |  |  | Analog Devices |  |  |  | MAX17048G+T10 | TDFN-8 Maxim |  | None |  | https://www.snapeda.com/api/url_track_click_mouser/?unipart_id=329239&manufacturer=Analog Devices&part_name=MAX17048G+T10&search_term=None | https://www.snapeda.com/parts/MAX17048G+T10/Analog+Devices/view-part/?ref=snap
X1 | 32MHz | NORDIC_NRF_XTAL_32MHZ | NORDIC_NRF_BT-XTAL_2016_N
X2 | 32.768kHz | NORDIC_NRF_1_XTAL_32KHZ | NORDIC_NRF_1_XTAL_3215_N

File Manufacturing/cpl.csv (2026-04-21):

ANT1 | 37.74 | 31.04 | 269.70 | 2450AT18B100E | 2450AT18B100E_ANTC3216X140N
C1 | 33.30 | 27.27 | 90.00 | 12pF | NORDIC_NRF_3_RESC0201_L
C1-EP-DR | 7.13 | 34.66 | 0.00 | 10uF | PERFECT_0402_0402
C10 | 25.40 | 29.69 | 0.00 | N.C. | NORDIC_NRF_3_RESC0201_L
C11 | 27.96 | 31.07 | 0.00 | 100pF | NORDIC_NRF_3_RESC0201_L
C12 | 20.90 | 29.93 | 90.00 | 100nF | NORDIC_NRF_3_RESC0201_L
C13 | 26.25 | 30.81 | 90.00 | N.C. | NORDIC_NRF_3_RESC0201_L
C14 | 18.79 | 28.40 | 180.00 | 4.7µF | PERFECT_0402_0402
C15 | 24.06 | 30.89 | 90.00 | 1.0µF | PERFECT_0402_0402
C16 | 25.17 | 30.80 | 90.00 | 47nF | NORDIC_NRF_3_RESC0201_L
C17 | 17.42 | 26.44 | 90.00 | 12pF | NORDIC_NRF_3_RESC0201_L
C18 | 17.36 | 25.01 | 90.00 | 12pF | NORDIC_NRF_3_RESC0201_L
C19 | 14.58 | 23.37 | 0.00 | 100nF | NORDIC_NRF_3_RESC0201_L
C2 | 33.16 | 29.00 | 90.00 | 12pF | NORDIC_NRF_3_RESC0201_L
C2-EP-DR | 3.76 | 33.83 | 0.00 | 4.7uF/25V | PERFECT_0402_0402
C20 | 21.66 | 20.60 | 269.80 | 4.7µF | PERFECT_0402_0402
C21 | 17.33 | 22.93 | 180.00 | 4.7µF | PERFECT_0402_0402
C22 | 35.00 | 31.05 | 0.00 | N.C. | NORDIC_NRF_3_RESC0201_L
C23 | 24.97 | 18.51 | 0.00 | 0.1uF | NORDIC_NRF_3_RESC0201_L
C24 | 28.07 | 18.37 | 0.00 | 10uF | NORDIC_NRF_3_RESC0201_L
C25 | 24.84 | 15.10 | 179.70 | 22uF | NORDIC_NRF_3_RESC0201_L
C27 | 19.45 | 11.04 | 88.10 | 0.1uF | NORDIC_NRF_3_RESC0201_L
C29 | 27.98 | 10.92 | 180.00 | 1uF | NORDIC_NRF_3_RESC0402_L
C3 | 31.57 | 31.49 | 0.00 | 1pF | NORDIC_NRF_3_RESC0201_L
C30 | 6.21 | 10.16 | 180.00 | 1uF | NORDIC_NRF_3_RESC0402_L
C31 | 19.83 | 9.57 | 180.00 | 1uF | NORDIC_NRF_3_RESC0402_L
C32 | 19.02 | 15.20 | 90.00 | 1uF | PERFECT_0402_0402
C33 | 26.51 | 14.41 | 0.00 | 22uF | NORDIC_NRF_3_RESC0201_L
C34 | 17.14 | 18.07 | 0.00 | 0.1uF | PERFECT_0402_0402
C37 | 22.69 | 18.25 | 90.10 | 1uF | PERFECT_0402_0402
C38 | 19.74 | 17.27 | 90.00 | 1uF | PERFECT_0402_0402
C39 | 21.30 | 15.09 | 0.00 | 10uF | PERFECT_0402_0402
C4 | 33.22 | 31.07 | 0.00 | 1pF | NORDIC_NRF_3_RESC0201_L
C42 | 19.08 | 30.27 | 0.00 | 0.1uF | NORDIC_NRF_3_RESC0201_L
C43 | 19.37 | 31.63 | 0.00 | 4.7uF | NORDIC_NRF_3_RESC0402_L
C5 | 19.37 | 29.35 | 180.00 | 100nF | NORDIC_NRF_3_RESC0201_L
C6 | 29.63 | 25.84 | 0.00 | 4.7µF | PERFECT_0402_0402
C7 | 19.46 | 22.89 | 0.00 | 100nF | NORDIC_NRF_3_RESC0201_L
C8 | 28.69 | 20.58 | 0.00 | 100nF | NORDIC_NRF_3_RESC0201_L
C9 | 28.08 | 25.19 | 90.00 | 820pF | NORDIC_NRF_3_RESC0201_L
D2 | -2.19 | 9.63 | 0.00 | MBR0530 | ESP32_C6_LIBRARY_5_SOD3716X135N
D3 | 14.41 | 29.95 | 270.00 | USBLC6-2SC6Y | ESP32_C6_LIBRARY_3_SOT95P280X145-6N
D4 | -0.52 | 7.00 | 0.00 | MBR0530 | ESP32_C6_LIBRARY_5_SOD3716X135N
D5 | -2.82 | 12.14 | 0.00 | MBR0530 | ESP32_C6_LIBRARY_5_SOD3716X135N
EPD_C1 | 7.59 | 23.78 | 0.00 | 1uF/50V | PERFECT_0402_0402
EPD_C10 | 6.84 | 13.15 | 0.00 | 1uF/50V | PERFECT_0402_0402
EPD_C11 | 4.09 | 13.57 | 0.00 | 1uF/50V | PERFECT_0402_0402
EPD_C12 | 1.94 | 13.76 | 180.00 | 1uF/50V | PERFECT_0402_0402
EPD_C2 | 7.57 | 25.01 | 0.00 | 1uF/50V | PERFECT_0402_0402
EPD_C5 | 5.84 | 21.93 | 0.00 | 0.1uF/50V | NORDIC_NRF_3_RESC0201_L
EPD_C6 | 8.09 | 19.29 | 0.00 | 1uF/50V | PERFECT_0402_0402
EPD_C7 | 8.35 | 17.66 | 0.00 | 1uF/50V | PERFECT_0402_0402
EPD_C8 | 9.36 | 12.89 | 0.00 | 1uF/50V | PERFECT_0402_0402
EPD_C9 | 1.51 | 11.33 | 0.00 | 1uF/50V | PERFECT_0402_0402
IC1 | 21.19 | 17.52 | 0.00 | BQ25180YBGR | BQ25180YBGR_BGA8C40P2X4_100X155X50
IC2 | 16.90 | 15.62 | 90.40 | DRV2605YZFR | DRV2605YZFR_BGA9C50P3X3_144X144X62
IC3 | 14.51 | 25.29 | 90.00 | BMA421 | BMA423_BMA423
IC9 | 26.00 | 16.82 | 0.00 | RT6160AWSC | RT6160AWSC_BGA15C40P3X5_140X230X60
J1 | 3.46 | 21.81 | 270.00 | 503480-2400 | 503480-2400_5034802400
J2 | 33.88 | 20.83 | 0.00 | TC2030-IDC | TC2030-IDC_TC2030IDC
J4 | 16.44 | 35.66 | 180.00 | KH-TYPE-C-16P | KH-TYPE-C-16P_KINGHELM_KH-TYPE-C-16P
L1 | 32.29 | 32.82 | 0.00 | 3.9nH | NORDIC_NRF_2_RESC0402_L
L2 | 21.88 | 30.32 | 90.00 | 10µH | NORDIC_NRF_2_RESC0402_L
L3 | 22.94 | 30.37 | 90.00 | 15nH | NORDIC_NRF_2_RESC0402_L
L5 | 8.11 | 30.11 | 90.00 | 68uH | ESP32_C6_LIBRARY_2_IND_4828-WE-TPC_WRE
L7 | 33.36 | 14.26 | 0.00 | FTC252012SR47MBCA | MLP2016SR47MT0S1_INDC2016X100N
Q1 | 8.35 | 21.49 | 90.00 | 20V/4.2A/52mΩ/1.4W | ESP32_C6_LIBRARY_4_ESP32_C6_LIBRARY_4_ESP32_C6_LIBRARY_4_ESP32_C6_LIBRARY_4_ESP32_WROVER_SPARKFUN-DISCRETESEMI_SOT23-3
Q3 | 3.16 | 31.90 | 0.00 | SI1308EDL-T1-GE3 | ESP32_C6_LIBRARY_6_SOT65P210X110-3N
R17 | 11.25 | 22.56 | 0.00 | 3K3 | CPF0201D7K68C1_0201
R18 | 15.51 | 21.93 | 91.00 | 3K3 | CPF0201D7K68C1_0201
R1_EP_DR | -0.46 | 31.53 | 180.00 | 0.47 | CPF0201D7K68C1_0201
R1_USB | 16.90 | 31.52 | 270.00 | 5K1 | CPF0201D7K68C1_0201
R2 | 24.58 | 16.27 | 0.00 | 0 | CPF0201D7K68C1_0201
R2_EP_DR | 0.21 | 33.41 | 180.00 | 10K | CPF0201D7K68C1_0201
R2_USB | 12.36 | 31.54 | 270.00 | 5K1 | CPF0201D7K68C1_0201
R3 | 12.25 | 25.49 | 0.00 | 0 | CPF0201D7K68C1_0201
R4 | 24.63 | 17.50 | 0.00 | 0 | CPF0201D7K68C1_0201
R5 | 7.71 | 10.24 | 180.00 | 10k | CPF0201D7K68C1_0201
R7 | 26.08 | 10.92 | 180.10 | 10k | CPF0201D7K68C1_0201
R8 | 13.93 | 9.08 | 0.00 | 10k | CPF0201D7K68C1_0201
R9 | 23.53 | 15.62 | 0.00 | 10K | CPF0201D7K68C1_0201
R_PWR_EPD | 10.53 | 22.53 | 0.00 | 10K | CPF0201D7K68C1_0201
R_TYPE_SEL | 10.74 | 20.56 | 0.00 | 2.2 | CPF0201D7K68C1_0201
SJ1 | 11.53 | 17.18 | 0.00 |  | ESP32_C6_LIBRARY_7_JUMPER_SJ
SW_DN | 27.63 | 8.04 | 180.00 | 2025-10-22_07-23-44_LIBRARY_EVP-AKE31ASW_EVP-AKE31A_PAN | 2025-10-22_07-23-44_LIBRARY_SW_EVP-AKE31A_PAN
SW_ENT | 16.70 | 8.09 | 180.00 | 2025-10-22_07-23-44_LIBRARY_EVP-AKE31ASW_EVP-AKE31A_PAN | 2025-10-22_07-23-44_LIBRARY_SW_EVP-AKE31A_PAN
SW_UP | 5.64 | 7.99 | 180.00 | 2025-10-22_07-23-44_LIBRARY_EVP-AKE31ASW_EVP-AKE31A_PAN | 2025-10-22_07-23-44_LIBRARY_SW_EVP-AKE31A_PAN
TP_3.3V | 14.64 | 19.38 | 0.00 | HECTOR_WATCH_1_TPTP20R | HECTOR_WATCH_1_TP20R
TP_3V3 | 28.26 | 33.73 | 0.00 | HECTOR_WATCH_1_TPTP20R | HECTOR_WATCH_1_TP20R
TP_BAT_GND | 35.98 | 11.48 | 0.00 | HECTOR_WATCH_1_TPTP20R | HECTOR_WATCH_1_TP20R
TP_GND | 37.95 | 14.74 | 0.00 | HECTOR_WATCH_1_TPTP20R | HECTOR_WATCH_1_TP20R
TP_ON | 26.27 | 12.61 | 0.00 | HECTOR_WATCH_1_TPTP20R | HECTOR_WATCH_1_TP20R
TP_OP | 23.38 | 7.15 | 0.00 | HECTOR_WATCH_1_TPTP20R | HECTOR_WATCH_1_TP20R
TP_RESET | 23.51 | 20.25 | 0.00 | HECTOR_WATCH_1_TPTP20R | HECTOR_WATCH_1_TP20R
TP_SCL | 12.12 | 14.78 | 0.00 | HECTOR_WATCH_1_TPTP20R | HECTOR_WATCH_1_TP20R
TP_SDA | 18.15 | 20.35 | 0.00 | HECTOR_WATCH_1_TPTP20R | HECTOR_WATCH_1_TP20R
TP_SWDCLK | 35.35 | 26.39 | 0.00 | HECTOR_WATCH_1_TPTP20R | HECTOR_WATCH_1_TP20R
TP_SWDIO | 38.19 | 26.20 | 0.00 | HECTOR_WATCH_1_TPTP20R | HECTOR_WATCH_1_TP20R
TP_SWO | 25.80 | 20.29 | 0.00 | HECTOR_WATCH_1_TPTP20R | HECTOR_WATCH_1_TP20R
TP_VBAT | 20.80 | 6.38 | 0.00 | HECTOR_WATCH_1_TPTP20R | HECTOR_WATCH_1_TP20R
TP_VREG | 22.95 | 10.28 | 0.00 | HECTOR_WATCH_1_TPTP20R | HECTOR_WATCH_1_TP20R
U1 | 23.97 | 25.60 | 0.00 | NRF52840_QF | NORDIC_NRF_4_AQFN50P700X700X85_HS-74N
U3 | 17.16 | 12.13 | 0.00 | MAX17048G+T10 | ESP32_C6_LIBRARY_SON50P200X200X80-9N
X1 | 31.06 | 28.07 | 0.00 | 32MHz | NORDIC_NRF_BT-XTAL_2016_N
X2 | 19.01 | 25.63 | 270.00 | 32.768kHz | NORDIC_NRF_1_XTAL_3215_N

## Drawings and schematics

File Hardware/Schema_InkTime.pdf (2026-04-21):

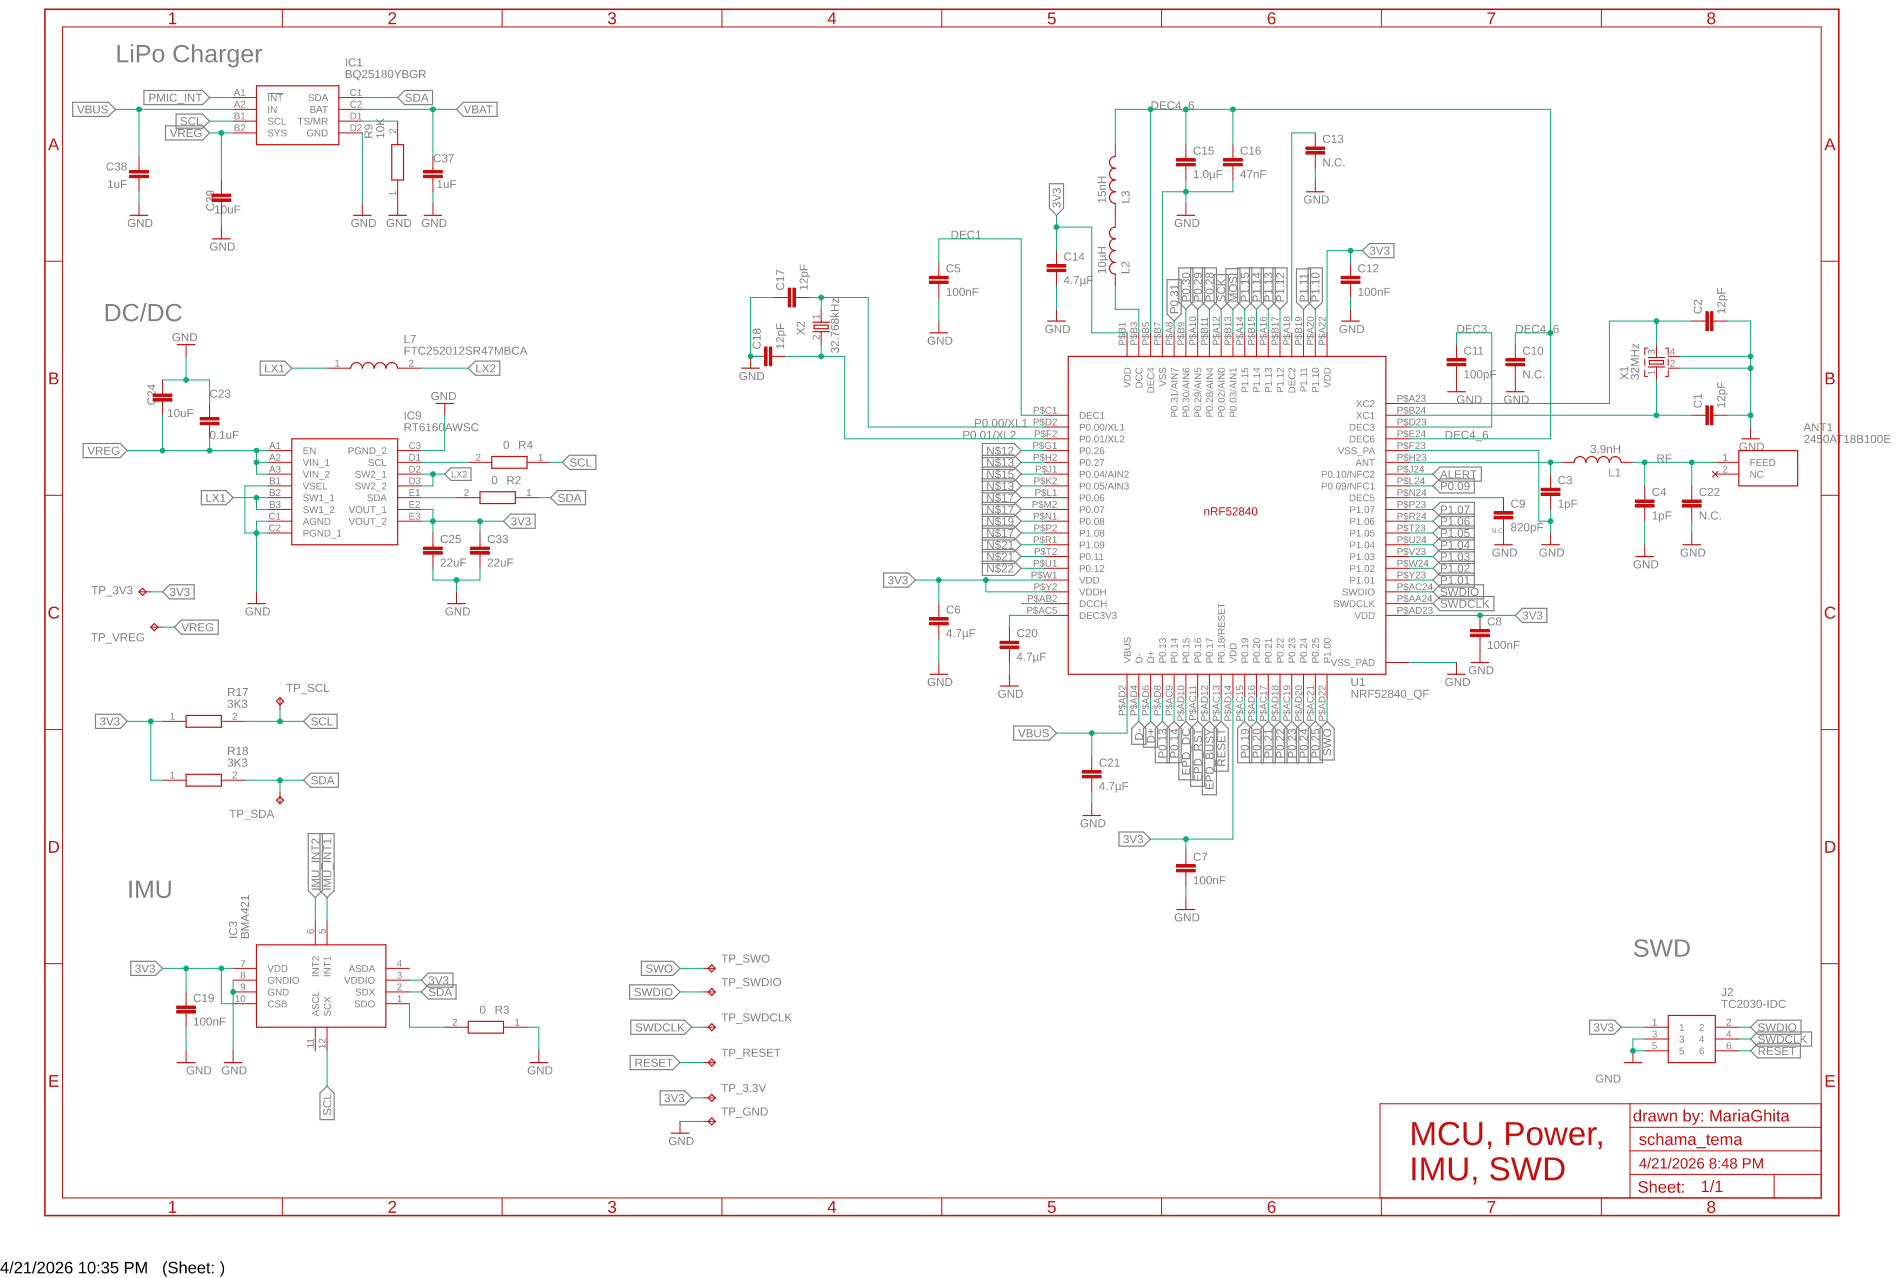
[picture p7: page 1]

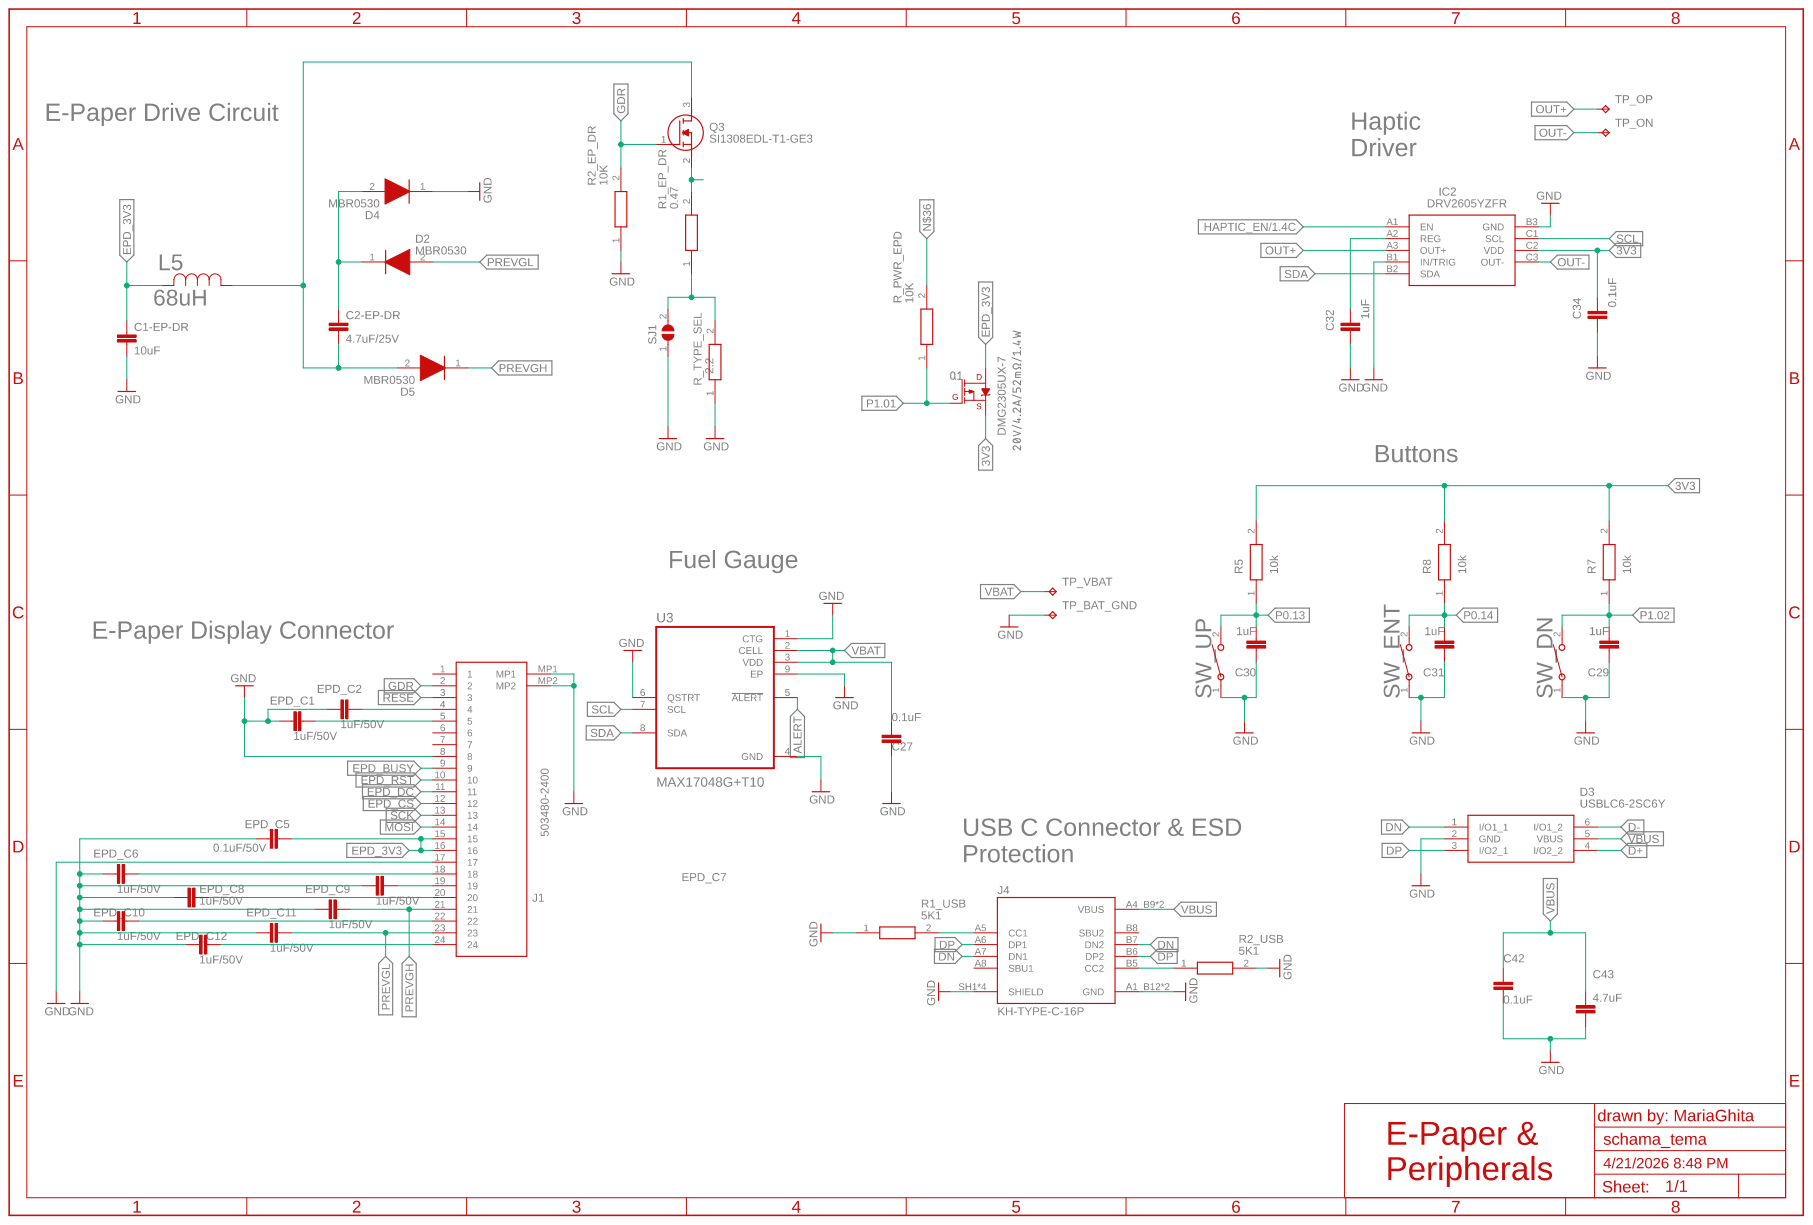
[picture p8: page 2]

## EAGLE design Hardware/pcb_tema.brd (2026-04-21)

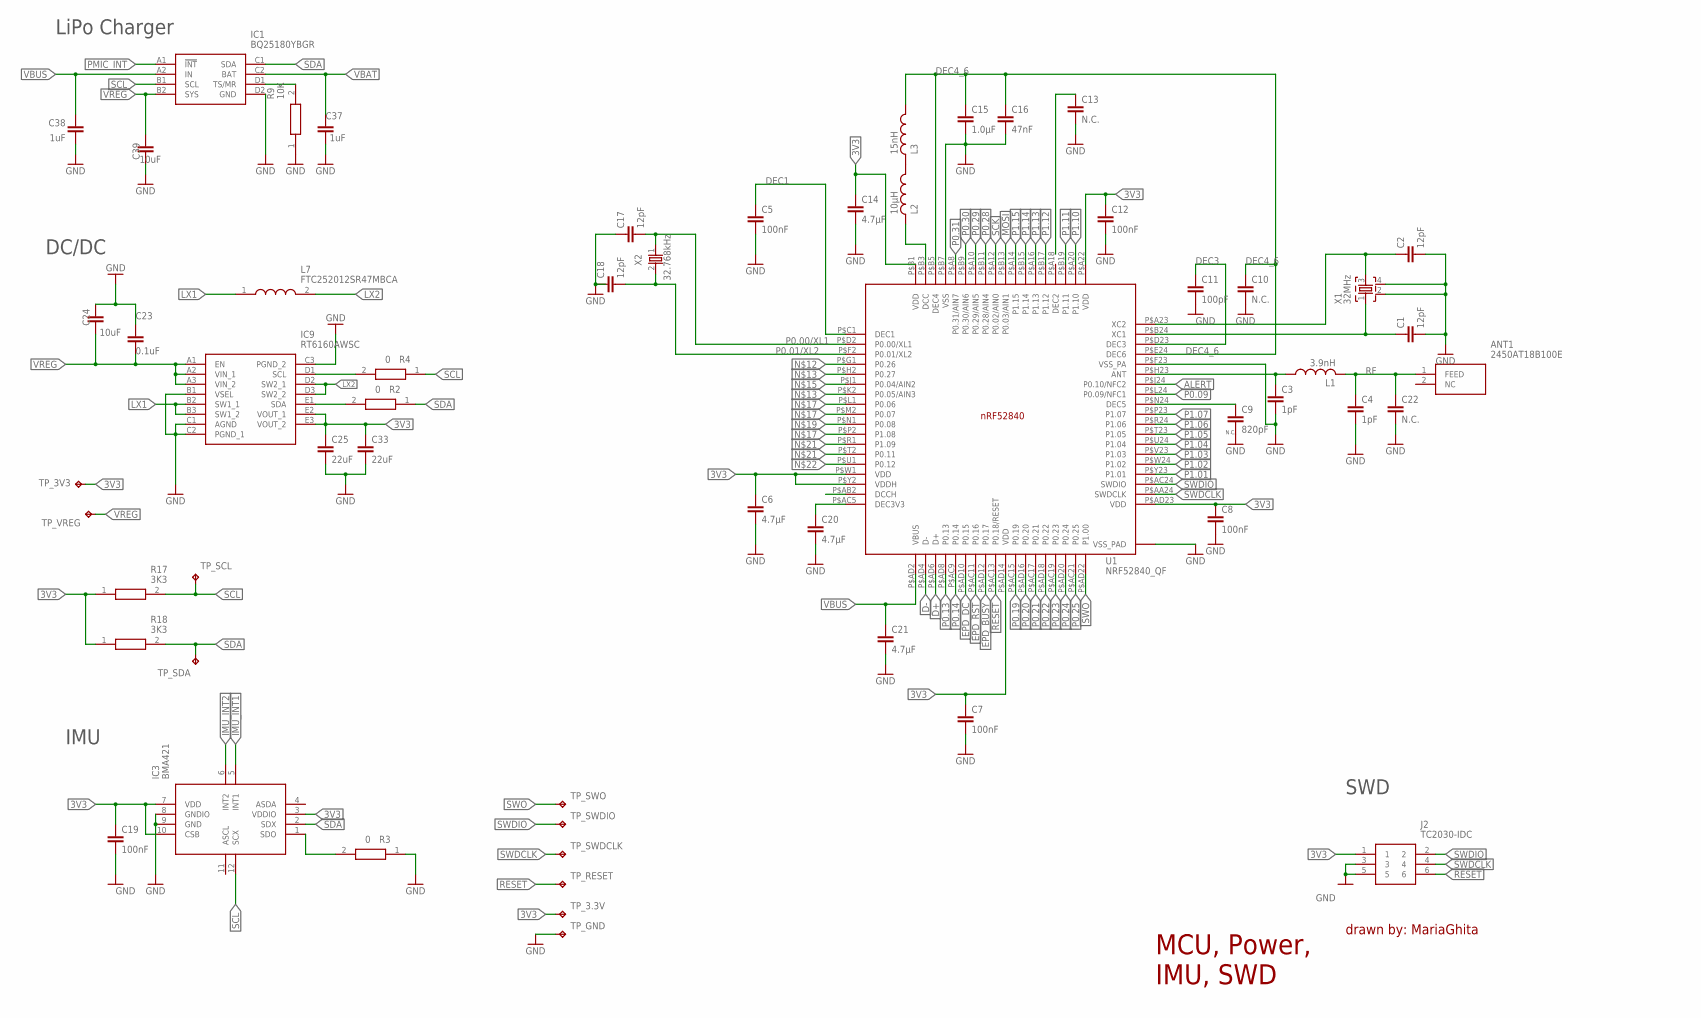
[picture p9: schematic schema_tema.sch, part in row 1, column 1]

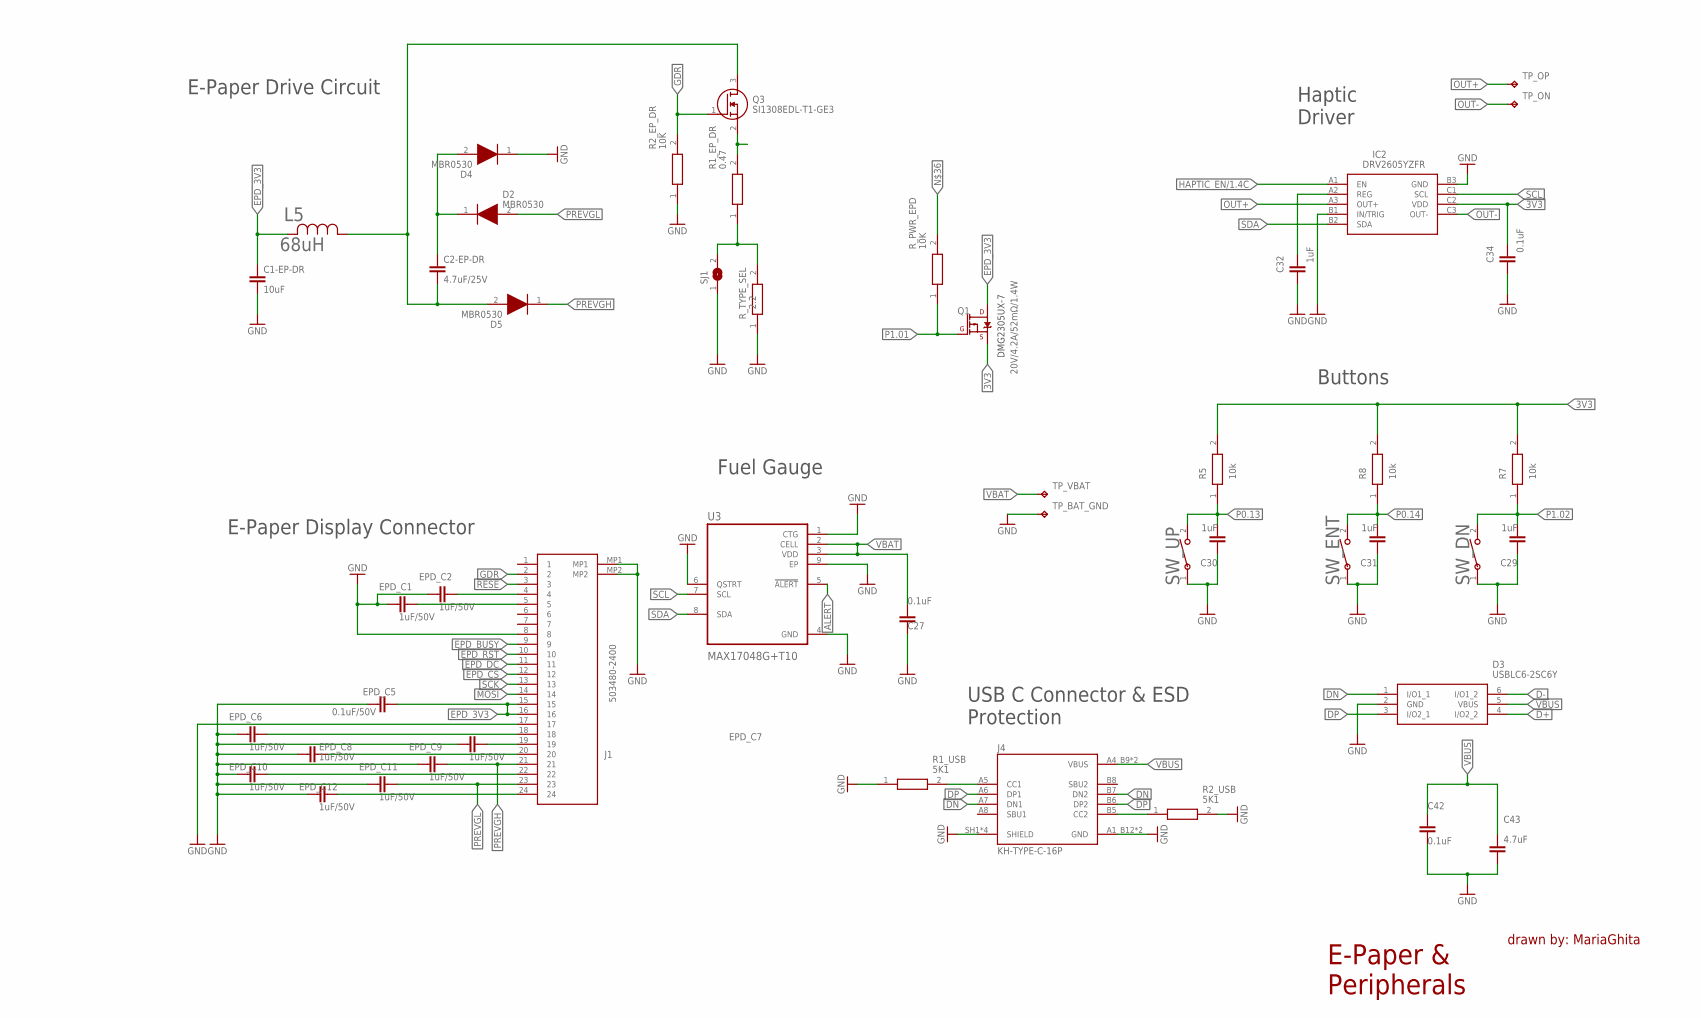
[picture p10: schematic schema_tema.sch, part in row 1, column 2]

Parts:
ANT1: 2450AT18B100E; 2450AT18B100E_ANTC3216X140N
C1, C2, C17, C18: 12pF; NORDIC_NRF_3_RESC0201_L
C1-EP-DR, C39: 10uF; PERFECT_0402_0402
C2-EP-DR: 4.7uF/25V; PERFECT_0402_0402
C3, C4: 1pF; NORDIC_NRF_3_RESC0201_L
C5, C7, C8, C12, C19: 100nF; NORDIC_NRF_3_RESC0201_L
C6, C14, C20, C21: 4.7µF; PERFECT_0402_0402
C9: 820pF; NORDIC_NRF_3_RESC0201_L
C10, C13, C22: N.C.; NORDIC_NRF_3_RESC0201_L
C11: 100pF; NORDIC_NRF_3_RESC0201_L
C15: 1.0µF; PERFECT_0402_0402
C16: 47nF; NORDIC_NRF_3_RESC0201_L
C23, C27, C42: 0.1uF; NORDIC_NRF_3_RESC0201_L
C24: 10uF; NORDIC_NRF_3_RESC0201_L
C25, C33: 22uF; NORDIC_NRF_3_RESC0201_L
C29, C30, C31: 1uF; NORDIC_NRF_3_RESC0402_L
C32, C37, C38: 1uF; PERFECT_0402_0402
C34: 0.1uF; PERFECT_0402_0402
C43: 4.7uF; NORDIC_NRF_3_RESC0402_L
D2, D4, D5: MBR0530; ESP32_C6_LIBRARY_5_SOD3716X135N
D3: USBLC6-2SC6Y; ESP32_C6_LIBRARY_3_SOT95P280X145-6N
EPD_C1, EPD_C2, EPD_C6, EPD_C7, EPD_C8, EPD_C9, EPD_C10, EPD_C11, EPD_C12: 1uF/50V; PERFECT_0402_0402
EPD_C5: 0.1uF/50V; NORDIC_NRF_3_RESC0201_L
IC1: BQ25180YBGR; BQ25180YBGR_BGA8C40P2X4_100X155X50
IC2: DRV2605YZFR; DRV2605YZFR_BGA9C50P3X3_144X144X62
IC3: BMA421; BMA423_BMA423
IC9: RT6160AWSC; RT6160AWSC_BGA15C40P3X5_140X230X60
J1: 503480-2400; 503480-2400_5034802400
J2: TC2030-IDC; TC2030-IDC_TC2030IDC
J4: KH-TYPE-C-16P; KH-TYPE-C-16P_KINGHELM_KH-TYPE-C-16P
L1: 3.9nH; NORDIC_NRF_2_RESC0402_L
L2: 10µH; NORDIC_NRF_2_RESC0402_L
L3: 15nH; NORDIC_NRF_2_RESC0402_L
L5: 68uH; ESP32_C6_LIBRARY_2_IND_4828-WE-TPC_WRE
L7: FTC252012SR47MBCA; MLP2016SR47MT0S1_INDC2016X100N
Q1: 20V/4.2A/52mΩ/1.4W; ESP32_C6_LIBRARY_4_ESP32_C6_LIBRARY_4_ESP32_C6_LIBRARY_4_ES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
Q3: SI1308EDL-T1-GE3; ESP32_C6_LIBRARY_6_SOT65P210X110-3N
R1_EP_DR: 0.47; CPF0201D7K68C1_0201
R1_USB, R2_USB: 5K1; CPF0201D7K68C1_0201
R2, R3, R4: 0; CPF0201D7K68C1_0201
R2_EP_DR, R9: 10K; CPF0201D7K68C1_0201
R5, R7, R8: 10k; CPF0201D7K68C1_0201
R17, R18: 3K3; CPF0201D7K68C1_0201
R_PWR_EPD: 10K; CPF0201D7K68C1_0201
R_TYPE_SEL: 2.2; CPF0201D7K68C1_0201
SJ1: ESP32_C6_LIBRARY_7_JUMPER_SJ
SW_DN: 2025-10-22_07-23-44_LIBRARY_EVP-AKE31ASW_EVP-AKE3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; 2025-10-22_07-23-44_LIBRARY_SW_EVP-AKE31A_PAN
SW_ENT: 2025-10-22_07-23-44_LIBRARY_EVP-AKE31ASW_EVP-AKE3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; 2025-10-22_07-23-44_LIBRARY_SW_EVP-AKE31A_PAN
SW_UP: 2025-10-22_07-23-44_LIBRARY_EVP-AKE31ASW_EVP-AKE3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; 2025-10-22_07-23-44_LIBRARY_SW_EVP-AKE31A_PAN
TP_3.3V, TP_3V3: HECTOR_WATCH_1_TPTP20R; HECTOR_WATCH_1_TP20R
TP_BAT_GND: HECTOR_WATCH_1_TPTP20R; HECTOR_WATCH_1_TP20R
TP_GND: HECTOR_WATCH_1_TPTP20R; HECTOR_WATCH_1_TP20R
TP_ON: HECTOR_WATCH_1_TPTP20R; HECTOR_WATCH_1_TP20R
TP_OP: HECTOR_WATCH_1_TPTP20R; HECTOR_WATCH_1_TP20R
TP_RESET: HECTOR_WATCH_1_TPTP20R; HECTOR_WATCH_1_TP20R
TP_SCL: HECTOR_WATCH_1_TPTP20R; HECTOR_WATCH_1_TP20R
TP_SDA: HECTOR_WATCH_1_TPTP20R; HECTOR_WATCH_1_TP20R
TP_SWDCLK: HECTOR_WATCH_1_TPTP20R; HECTOR_WATCH_1_TP20R
TP_SWDIO: HECTOR_WATCH_1_TPTP20R; HECTOR_WATCH_1_TP20R
TP_SWO: HECTOR_WATCH_1_TPTP20R; HECTOR_WATCH_1_TP20R
TP_VBAT: HECTOR_WATCH_1_TPTP20R; HECTOR_WATCH_1_TP20R
TP_VREG: HECTOR_WATCH_1_TPTP20R; HECTOR_WATCH_1_TP20R
U1: NRF52840_QF; NORDIC_NRF_4_AQFN50P700X700X85_HS-74N
U3: MAX17048G+T10; ESP32_C6_LIBRARY_SON50P200X200X80-9N
X1: 32MHz; NORDIC_NRF_BT-XTAL_2016_N
X2: 32.768kHz; NORDIC_NRF_1_XTAL_3215_N

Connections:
3V3: C6.1, C7.1, C8.1, C12.1, C14.1, C19.1, C34.1, IC2.C2 (VDD), IC3.3 (VDDIO), IC3.7 (VDD), IC3.10 (CSB), J2.1, Q1.2 (S), R5.2, R7.2, R8.2, R17.1, R18.1, TP_3.3V.TP, TP_3V3.TP, U1.P$A22 (VDD), U1.P$AD14 (VDD), U1.P$AD23 (VDD), U1.P$B1 (VDD), U1.P$W1 (VDD), U1.P$Y2 (VDDH)
ALERT: U1.P$J24 (P0.10/NFC2), U3.5 (!ALERT)
D+: D3.4 (I/O2_2), U1.P$AD6 (D+)
D-: D3.6 (I/O1_2), U1.P$AD4 (D-)
DEC4_6: C10.1, C15.1, C16.1, L3.1, U1.P$B5 (DEC4), U1.P$E24 (DEC6)
DN: D3.1 (I/O1_1), J4.A7 (DN1), J4.B7 (DN2)
DP: D3.3 (I/O2_1), J4.A6 (DP1), J4.B6 (DP2)
EPD_3V3: C1-EP-DR.1, EPD_C5.2, J1.15, J1.16, L5.2, Q1.3 (D)
EPD_BUSY: J1.9, U1.P$AD12 (P0.17)
EPD_CS: J1.12
EPD_DC: J1.11, U1.P$AD10 (P0.15)
EPD_RST: J1.10, U1.P$AC11 (P0.16)
GDR: J1.2, Q3.1 (G), R2_EP_DR.2
GND: C1.2, C1-EP-DR.2, C2.2, C3.2, C4.2, C5.2, C6.2, C7.2, C8.2, C9.2, C10.2, C11.2, C12.2, C13.2, C14.2, C15.2, C16.2, C17.1, C18.1, C19.2, C20.2, C21.2, C22.2, C23.1, C24.2, C25.2, C27.2, C29.1, C30.1, C31.1, C32.2, C33.2, C34.2, C37.1, C38.1, C39.2, C42.2, C43.2, D3.2 (GND), D4.1 (K), EPD_C1.2, EPD_C2.2, EPD_C5.1, EPD_C6.2, EPD_C7.2, EPD_C8.2, EPD_C9.2, EPD_C10.2, EPD_C11.2, EPD_C12.2, IC1.D2 (GND), IC2.B1 (IN/TRIG), IC2.B3 (GND), IC3.8 (GNDIO), IC3.9 (GND), IC9.B1 (VSEL), IC9.C1 (AGND), IC9.C2 (PGND_1), IC9.C3 (PGND_2), J1.8, J1.17, J1.MP1, J1.MP2, J2.3, J2.5, J4.A1_B12 (GND), J4.A12_B1 (GND), J4.SH1 (SHIELD), J4.SH2 (SHIELD), J4.SH3 (SHIELD), J4.SH4 (SHIELD), R1_USB.1, R2_EP_DR.1, R2_USB.2, R3.1, R9.1, R_TYPE_SEL.1, SJ1.1, SW_DN.1, SW_ENT.1, SW_UP.1, TP_BAT_GND.TP, TP_GND.TP, U1.P$74 (VSS_PAD), U1.P$75 (VSS_PAD), U1.P$76 (VSS_PAD), U1.P$77 (VSS_PAD), U1.P$78 (VSS_PAD), U1.P$79 (VSS_PAD), U1.P$80 (VSS_PAD), U1.P$81 (VSS_PAD), U1.P$82 (VSS_PAD), U1.P$83 (VSS_PAD), U1.P$84 (VSS_PAD), U1.P$85 (VSS_PAD), U1.P$86 (VSS_PAD), U1.P$87 (VSS_PAD), U1.P$88 (VSS_PAD), U1.P$89 (VSS_PAD), U1.P$90 (VSS_PAD), U1.P$B7 (VSS), U1.P$F23 (VSS_PA), U3.1 (CTG), U3.4 (GND), U3.6 (QSTRT), U3.9 (EP), X1.2, X1.4
HAPTIC_EN/1.4C: IC2.A1 (EN)
IMU_INT1: IC3.5 (INT1)
IMU_INT2: IC3.6 (INT2)
LX1: IC9.B2 (SW1_1), IC9.B3 (SW1_2), L7.1
LX2: IC9.D2 (SW2_1), IC9.D3 (SW2_2), L7.2
MOSI: J1.14, U1.P$B13 (P0.03/AIN1)
unnamed: IC9.D1 (SCL), R4.2
unnamed: IC9.E1 (SDA), R2.2
unnamed: C25.1, C33.1, IC9.E2 (VOUT_1), IC9.E3 (VOUT_2)
unnamed: IC1.D1 (TS/MR), R9.2
unnamed: C5.1, U1.P$C1 (DEC1)
unnamed: L2.2, U1.P$B3 (DCC)
unnamed: IC3.1 (SDO), R3.2
unnamed: L2.1, L3.2
unnamed: C11.1, U1.P$D23 (DEC3)
unnamed: C20.1, U1.P$AC5 (DEC3V3)
unnamed: C9.1, U1.P$N24 (DEC5)
unnamed: C2.1, U1.P$A23 (XC2), X1.3
unnamed: C1.1, U1.P$B24 (XC1), X1.1
unnamed: C3.1, L1.1, U1.P$H23 (ANT)
unnamed: C2-EP-DR.1, D2.1 (K), D4.2 (A)
unnamed: C2-EP-DR.2, D5.2 (A), L5.1, Q3.3 (D)
unnamed: Q3.2 (S), R1_EP_DR.2
unnamed: R1_EP_DR.1, R_TYPE_SEL.2, SJ1.2
unnamed: EPD_C1.1, J1.5
unnamed: C32.1, IC2.A2 (REG)
unnamed: EPD_C6.1, J1.18
unnamed: EPD_C7.1, J1.19
unnamed: EPD_C2.1, J1.4
unnamed: EPD_C8.1, J1.20
unnamed: J4.A5 (CC1), R1_USB.2
unnamed: EPD_C10.1, J1.22
unnamed: EPD_C12.1, J1.24
unnamed: J4.B5 (CC2), R2_USB.1
OUT+: IC2.A3 (OUT+), TP_OP.TP
OUT-: IC2.C3 (OUT-), TP_ON.TP
P0.00/XL1: C17.2, U1.P$D2 (P0.00/XL1), X2.1
P0.01/XL2: C18.2, U1.P$F2 (P0.01/XL2), X2.2
P0.09: U1.P$L24 (P0.09/NFC1)
P0.13: C30.2, R5.1, SW_UP.2, U1.P$AD8 (P0.13)
P0.14: C31.2, R8.1, SW_ENT.2, U1.P$AC9 (P0.14)
P0.19: U1.P$AC15 (P0.19)
P0.20: U1.P$AD16 (P0.20)
P0.21: U1.P$AC17 (P0.21)
P0.22: U1.P$AD18 (P0.22)
P0.23: U1.P$AC19 (P0.23)
P0.24: U1.P$AD20 (P0.24)
P0.25: U1.P$AC21 (P0.25)
P0.28: U1.P$B11 (P0.28/AIN4)
P0.29: U1.P$A10 (P0.29/AIN5)
P0.30: U1.P$B9 (P0.30/AIN6)
P0.31: U1.P$A8 (P0.31/AIN7)
P1.01: Q1.1 (G), R_PWR_EPD.1, U1.P$Y23 (P1.01)
P1.02: C29.2, R7.1, SW_DN.2, U1.P$W24 (P1.02)
P1.03: U1.P$V23 (P1.03)
P1.04: U1.P$U24 (P1.04)
P1.05: U1.P$T23 (P1.05)
P1.06: U1.P$R24 (P1.06)
P1.07: U1.P$P23 (P1.07)
P1.10: U1.P$A20 (P1.10)
P1.11: U1.P$B19 (P1.11)
P1.12: U1.P$B17 (P1.12)
P1.13: U1.P$A16 (P1.13)
P1.14: U1.P$B15 (P1.14)
P1.15: U1.P$A14 (P1.15)
PMIC_INT: IC1.A1 (!INT)
PREVGH: D5.1 (K), EPD_C9.1, J1.21
PREVGL: D2.2 (A), EPD_C11.1, J1.23
RESE: J1.3
RESET: J2.6, TP_RESET.TP, U1.P$AC13 (P0.18/RESET)
RF: ANT1.1 (FEED), C4.1, C22.1, L1.2
SCK: J1.13, U1.P$A12 (P0.02/AIN0)
SCL: IC1.B1 (SCL), IC2.C1 (SCL), IC3.12 (SCX), R17.2, TP_SCL.TP, U3.7 (SCL)
SDA: IC1.C1 (SDA), IC2.B2 (SDA), IC3.2 (SDX), R18.2, TP_SDA.TP, U3.8 (SDA)
SWDCLK: J2.4, TP_SWDCLK.TP, U1.P$AA24 (SWDCLK)
SWDIO: J2.2, TP_SWDIO.TP, U1.P$AC24 (SWDIO)
SWO: TP_SWO.TP, U1.P$AD22 (P1.00)
VBAT: C27.1, C37.2, IC1.C2 (BAT), TP_VBAT.TP, U3.2 (CELL), U3.3 (VDD)
VBUS: C21.1, C38.2, C42.1, C43.1, D3.5 (VBUS), IC1.A2 (IN), J4.A4_B9 (VBUS), J4.A9_B4 (VBUS), U1.P$AD2 (VBUS)
VREG: C23.2, C24.1, C39.1, IC1.B2 (SYS), IC9.A1 (EN), IC9.A2 (VIN_1), IC9.A3 (VIN_2), TP_VREG.TP

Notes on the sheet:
LiPo Charger
DC/DC
IMU
SWD
E-Paper Drive Circuit
DMG2305UX-7
Haptic Driver
E-Paper Display Connector
Buttons
Fuel Gauge
USB C Connector & ESD Protection
N.C.
drawn by: MariaGhita
MCU, Power, IMU, SWD
E-Paper & Peripherals

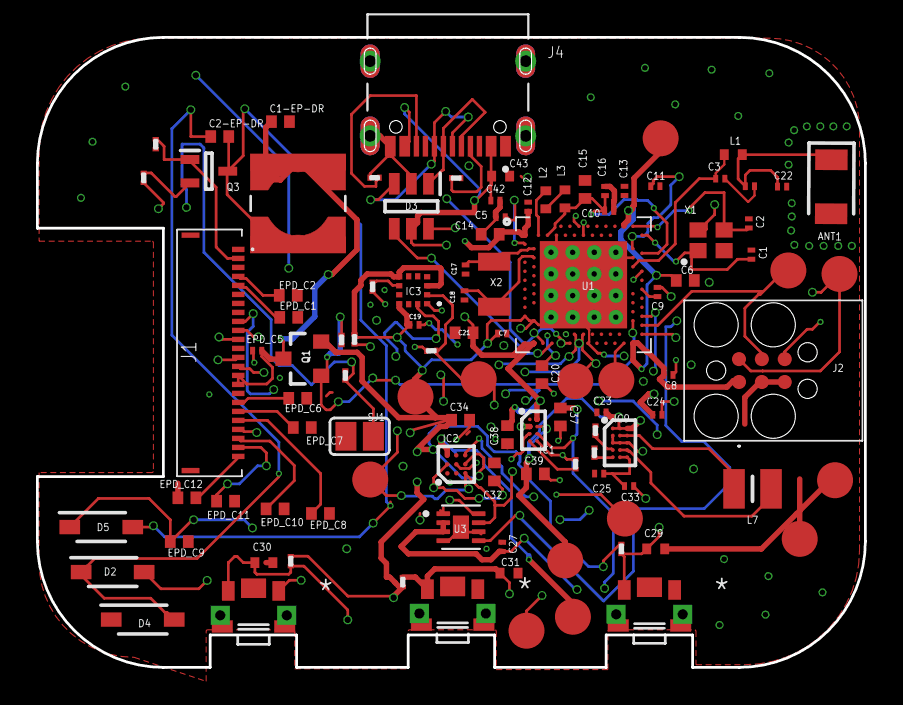
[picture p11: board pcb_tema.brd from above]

Board: 4 copper layers, 46.0 x 35.0 mm, 105 parts (0 on the bottom side), 65 nets.

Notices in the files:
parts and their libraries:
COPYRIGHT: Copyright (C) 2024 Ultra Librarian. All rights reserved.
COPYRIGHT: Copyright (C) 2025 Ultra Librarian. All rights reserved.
